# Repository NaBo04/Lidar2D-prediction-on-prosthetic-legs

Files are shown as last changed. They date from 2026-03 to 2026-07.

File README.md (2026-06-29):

# Contenido de este Repositorio :books:

    - Codgios: Contiene los códigos finales utilizados para la captura de datos, la ejecución, 
        construcción y entrenamiento de la red, el uso del dispositivo final, el entorno virtual.
        entre otros. 
    - DocumentosDeInvestigacion: Contiene los documentos externos utilizados durante el proyecto,
        como pueden ser datasheets, papers y documentos del curso.
    - DiseñosPCB: Archivos gerber de las versiones finales de las PCB usadas.
    - Entregables: Incluye los informes, presentaciones o similar, desarrollados por el equipo para
        las entregas del curso.
    - Modelos3D: Modelos diseñados para la implementación final de la muslera y la carcasa para la
        prótesis.

# Links importantes :rocket:

    - Notion (Carta Gantt): https://www.notion.so/Proyecto-de-t-tulo-3273d8bd994380379207d7b755e2225a
    - Drive (Videos): https://drive.google.com/drive/folders/1dMPfvoMqhFyon8SmyaXOXM7CERQkg4x7?usp=drive_link

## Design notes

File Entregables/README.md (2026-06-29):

\# Acá la presentación #

Link Video de Validación de Funcionamiento LIDAR: 
    https://drive.google.com/drive/folders/1dMPfvoMqhFyon8SmyaXOXM7CERQkg4x7?usp=sharing

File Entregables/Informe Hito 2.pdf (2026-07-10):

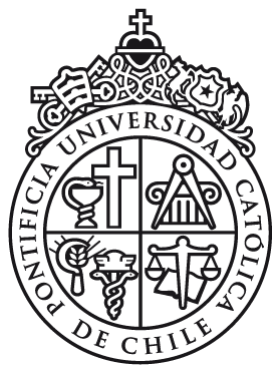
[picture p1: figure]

### PONTIFICIA UNIVERSIDAD CATOLICA DE CHILE ´

### ESCUELA DE INGENIERÍA

### DEPARTAMENTO DE INGENIERÍA ELECTRICA ´

# Informe final - Integración LIDAR 2D

# para Anticipación de Terreno en

# Prótesis Transfemoral Activa

PROYECTO DE TÍTULO - IEE3112

Profesor: Felipe Nuñez

Grupo 2

28 de junio del 2026

## Índice

1 Hito 1: Propuesta Conceptual y Diseño Funcional | 4
2 Hito 2: Prototipo | 21
2.4.2 | Detección y estimación de inclinación de rampas y del plano de suelo | 32

2.5 Validación de latencia extremo a extremo menor o igual a 200 ms | | 33
2.6 Métricas de error y matriz de confusión | | 33

2.7 Validación experimental en entorno controlado con medición de errores geométri-

cos | | 35
2.8 Repositorio GitHub documentado | | 36
2.9 Manual técnico de integración, arquitectura y pruebas | | 36
2.10 Presupuesto final | | 36
3 Anexo | 39

## Índice de figuras

Figura 1 | Diagrama de Bloques de Alto Nivel | | 4
Figura 2 | Leyenda | | 4
Figura 3 | Diagrama de Bloques de Bajo Nivel (Completo) | | 5
Figura 4 | Diagrama de Bloques de Bajo Nivel (Parte 1) | | 5
Figura 5 | Diagrama de Bloques de Bajo Nivel (Parte 2) | | 6
Figura 6 | Batería para validación experimental | | 8
Figura 7 | Diferentes topologías ML | | 15
Figura 8 | Representación de la pierna y su modelo asociado | | 16
Figura 9 | Curvatura de la pierna | | 17
Figura 10 | Soporte mecánico - Diseño 3D | | 17
Figura 11 | Soporte mecánico - Aplicación Física | | 18
Figura 12 | Soporte mecánico diseñado para la prótesis | | 21
Figura 13 | Solapas del soporte mecánico diseñado para la prótesis | | 22
Figura 14 | Diseño de Placas en Software EasyEDA | | 23
Figura 15 | Ambas PCB montadas una sobre otra en aplicación final | | 24
Figura 16 | Diagrama red iteración 1 | | 28
Figura 17 | Diagrama red iteración 2 | | 29
Figura 18 | Pagina Local para la Toma de Muestras | | 30
Figura 19 | Imágenes de Ejemplo de Adquisición de Datos | | 31

Figura 20 | Latencia | | 33
Figura 21 | Matriz de confusión sobre Test-dataset para datos binarios | | 34

## Índice de tablas

Tabla 1 | Especificaciones de componentes para integración de LIDAR en próte-
| sis transfemoral activa | | 13
Tabla 2 | Tabla con principales consumos | | 14
Tabla 3 | Presupuesto Hito 1 | | 20
Tabla 4 | Tabla con principales consumos | | 24
Tabla 5 | Etiquetado | | 27
Tabla 6 | Métricas de error para 100 épocas de entrenamiento | | 33
Tabla 7 | Presupuesto Hito 2 | | 38

## 1. Hito 1: Propuesta Conceptual y Diseño Funcional

### 1.1. Arquitectura general del sistema

La siguiente figura muestra el diagrama de bloques de alto nivel, el cuál entrega una primera

idea simplificada de cuál es el flujo del sistema en su totalidad. A modo de explicación, el

sistema inicia con un bloque de sensores que miden el entorno, los cuáles entregan medidas a la

Raspberry Pi 5. Esta se encarga del procesamiento de las medidas, la predicción mediante uso

de algoritmos de Machine Learning y la posterior comunicación para validación del usuario

monitor. El objetivo es que las predicciones sirvan para ejecutar una reacción por parte de

la prótesis, aunque se escapa de los objetivos de este proyecto. Finalmente, el sistema posee

su sub-sistema de alimentación, que le otorga independencia.

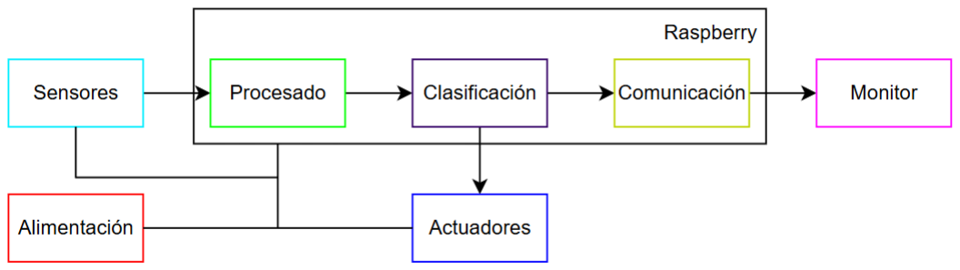
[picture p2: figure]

Figura 1: Diagrama de Bloques de Alto Nivel

Como se puede observar en la figura, los bloques siguen cierto código de colores, el cuál se

detalla en la leyenda a continuación.

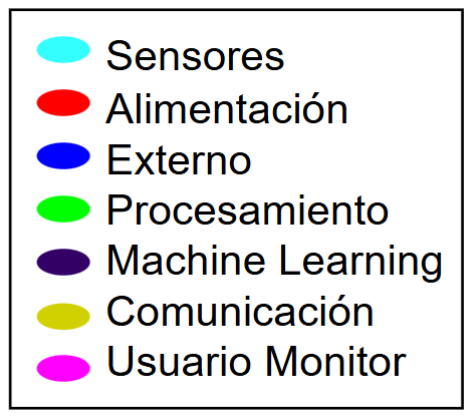
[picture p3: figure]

Figura 2: Leyenda

Una vez entendido el sistema de manera general, se puede proceder a analizar el diagrama

de bloques de bajo nivel. El cual, es escala macro, se ve como sigue. Luego, se detallará cada

sub-sistema con detenimiento.

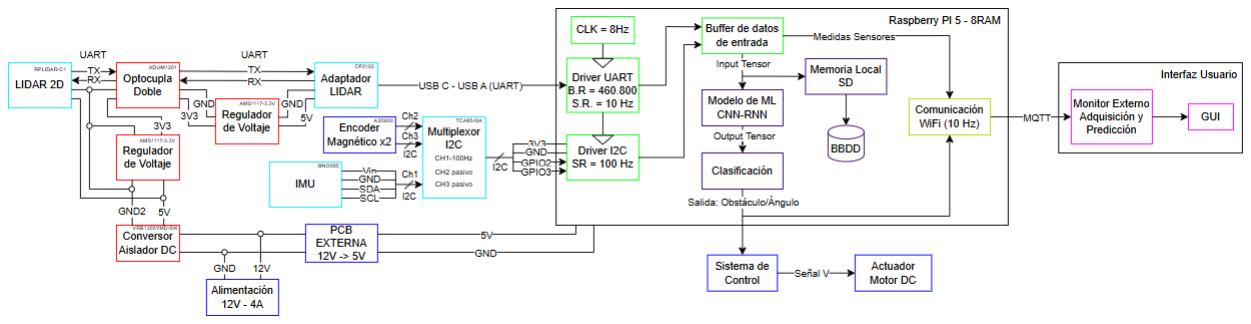
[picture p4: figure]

Figura 3: Diagrama de Bloques de Bajo Nivel (Completo)

Por motivos de la baja resolución de este en el informe, se procede a analizar el diagrama

por partes.

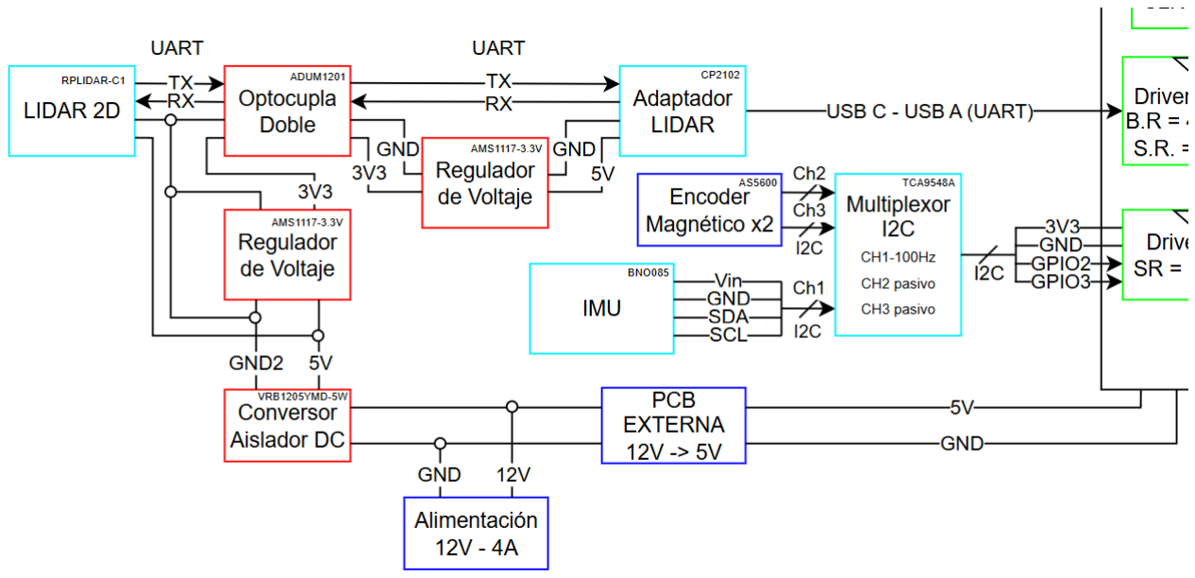
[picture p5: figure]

Figura 4: Diagrama de Bloques de Bajo Nivel (Parte 1)

La primera parte de este diagrama, incluye los bloques de sensores en color celeste, alimen-

tación y considera elementos externos. Esta parte es lo que concentra la mayor parte del

Hardware del sistema. En cuanto a los sensores, se aprecian el sensor principal: el LIDAR, la unidad de medición inercial (IMU) y sus adaptadores. Lo relacionado al LIDAR funciona

mediante protocolo UART, mientras que lo relacionado al IMU usa protocolo I2C. Por otra

parte, en color rojo, se encuentra lo relacionado a la alimentación. Estos bloques aparecen

principalmente para alimentar correctamente, y sobre todo proteger el sensor LIDAR y ais-

larlo contra posibles amenazas, por su sensibilidad y costo. Se explicará más en detalle en las

secciones correspondientes. Finalmente, en color azul, se encuentran elementos externos que

ya forman parte del proyecto, pero que decidimos tomar en consideración, para una correcta

cohesión con el desarrollo del proyecto. Estas son la alimentación de las baterías actuales, la

PCB del sistema de baterías y los encoders magnéticos.

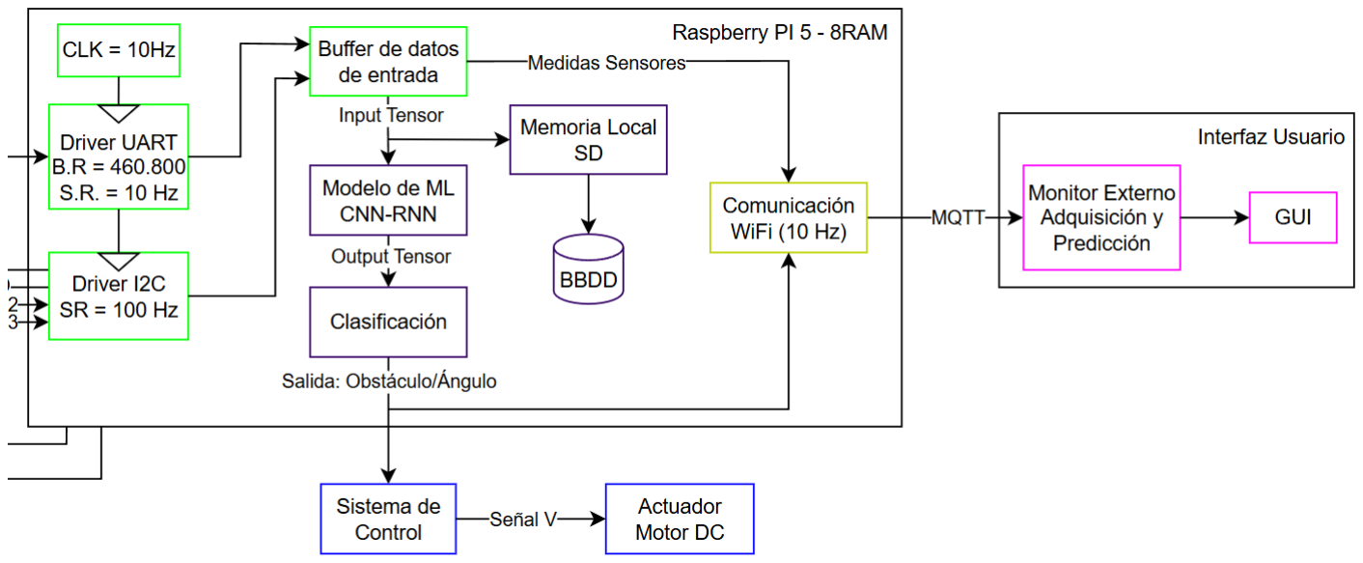
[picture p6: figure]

Figura 5: Diagrama de Bloques de Bajo Nivel (Parte 2)

La segunda parte de este diagrama incluye los sub-sistemas de procesamiento, predicción,

comunicación y monitoreo de usuario. La primera parte, en color verde, muestra la coordina-

ción de los 2 sistemas de adquisición de datos mediante los sensores, para formar los datos de

entrada para el modelo de red neuronal. Luego, en color morado, se encuentra lo relacionado

al algoritmo de predicción como tal, lo que incluye también la toma y guardado de datos

de forma local, para usarlos a lo largo del entrenamiento del modelo. En color amarillo, se

incluye el bloque de comunicación, que servirá durante las implementaciones finales y de-

bugueo correspondiente. Al final de la cadena, en rosado, está el bloque que corresponde al

monitoreo del sistema de forma remota, mediante una interfaz para el usuario. Por último, en la imagen se aprecian 2 bloques de color azul, que nuevamente son funciones externas al

objetivo del proyecto, relacionadas al sistema de reacción/actuación frente a la predicción.

### 1.2. Definición de bloques funcionales

### 1.2.1. Fuente de alimentación

La prótesis transfemoral activa ya cuenta con una batería integrada que alimenta la electróni-

ca de control existente. Esta misma fuente de energía será utilizada para suministrar potencia

a los nuevos subsistemas de percepción (LIDAR e IMU).

Dado que la batería ya se encuentra dimensionada y validada para la operación de la prótesis,

no es responsabilidad de este proyecto redefinir, reemplazar o caracterizar la fuente de ali-

mentación. En su lugar, nos enfocamos en asegurar que los nuevos componentes (RPLIDAR

C1 e IMU BNO085) sean compatibles con los niveles de voltaje y corriente disponibles en el

sistema existente.

La integración se realiza mediante un convertidor DC-DC aislado modelo VRB1205YMD de

12 a 5 V de 5 W, que permite adaptar la tensión de la batería a los requerimientos específicos

del LIDAR (4.8-5.2V a 260 mA típico) y para poder suministrar la corriente peak del Lidar

(1A en la partida). Este convertidor actúa como interfaz entre la fuente centralizada de la

prótesis y los nuevos sensores, protegiendo ambos subsistemas de variaciones en la tensión

de la batería. Mientras que la IMU (3-5V a 3-5 mA) se alimentará desde la misma fuente

utilizada por la Raspberry 5 Pi. Para las fases de prototipado y validación experimental, se

utilizará una batería portátil de 5000 mAh que proporciona conexión USB estándar y voltaje

de salida 5V.

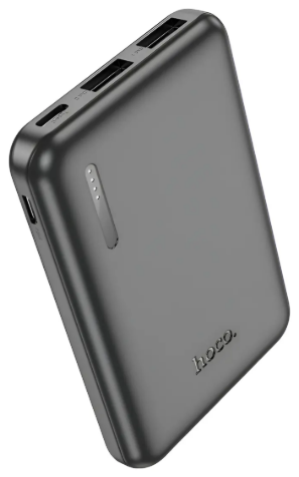
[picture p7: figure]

Figura 6: Batería para validación experimental

### 1.2.2. Módulo LIDAR 2D

Para este proyecto se utilizará el modelo RPLIDAR C1, el cual tiene un rango de medición

de 12 metros para objetos claros y de 6 para oscuros. Además, presenta una frecuencia de

muestreo de 5 kHz, un campo de visión 360° y una precisión de ± 30 mm.

Utiliza un puerto TTL UART con un baud rate de 460,800 bps para proporcionar información

de distancia (mm), ángulo (grados), señal de inicio de escaneo y datos de reflectividad (2.5D).

Los requerimientos de funcionamiento son principalmente una alimentación de 5 V y 230 mA.

El dispositivo es ligero, tiene un peso aproximado de 110 g, y es resistente a polvo y salpi-

caduras. Sin embargo, se debe tener la precaución de no exponer el láser directamente al sol

puesto que podría dañar irreversiblemente su funcionamiento.

### 1.2.3. Aislación del Módulo LIDAR 2D

Un LiDAR 2D es un sensor electromecánico de operación continua. Por esta razón, compartir

la misma referencia de tierra con una Raspberry Pi 5 puede ocasionar diversos inconvenientes.

El primero de ellos es la inyección de ruido electromecánico. Los motores, al ser cargas

inductivas, junto con su conmutación electrónica, generan picos de voltaje que se inyectan directamente en el plano de tierra. Otro problema importante son las corrientes de irrupción

(inrush), que consisten en corrientes transitorias de arranque capaces de provocar caídas

momentáneas de tensión, comprometiendo así la estabilidad de los rieles de alimentación de

la Raspberry Pi 5.

La solución a estos problemas es la aislación galvánica del motor con el sistema de control,

tanto para proteger el LIDAR 2D como la Raspberry Pi 5. Tal como se mencionó en etapas

anteriores, se utiliza un conversor DC-DC tipo Buck conectado en el lado de alto voltaje a

12V desde la batería (ya integrada en la prótesis) y en la lado de bajo voltaje a 5V conectado

a los rieles de alimentación del LIDAR 2D.

Para mantener el aislamiento galvánico en las líneas de comunicación entre la Raspberry Pi 5

y el LiDAR 2D, se implementará el aislador digital ADuM1201. Dado que los niveles lógicos

de salida de este módulo dependen exclusivamente de las tensiones aplicadas a sus rieles de

alimentación, y considerando que tanto el LiDAR 2D como el adaptador USB operan con

lógica de 3.3 V, resulta importante el uso de dos reguladores de tensión AMS1117-3.3 para

fijar dicho voltaje en ambos extremos del circuito.

### 1.2.4. Plataforma de procesamiento embebido (Raspberry Pi 5)

La Raspberry Pi 5 es una pequeño computador de bajo costo con un rendimiento sorprendente

para su tamaño. Su procesador cuádruple núcleo a 2.4 GHz la hace entre 2 y 3 veces más

rápida que la versión anterior, y su chip gráfico alcanza cerca de 0.077 TFLOPS, suficiente

para tareas de ML. Incluye WiFi de doble banda y Bluetooth 5.0, lo que facilita su conexión

inalámbrica en cualquier entorno. También estrena una ranura PCIe que permite conectar

discos SSD de alta velocidad, algo nunca visto en versiones anteriores. Con hasta 16 GB

de memoria RAM y un consumo eléctrico muy bajo, es ideal para proyectos embebidos,

automatización y computación en el borde de la red.

### 1.2.5. Sistema de comunicación

Los bloques funcionales presentados previamente necesitan transmitir datos entre ellos para

un correcto funcionamiento del sistema. En general los distintos bloques comunican o reciben datos desde la Raspberry, que actúa en este caso como nodo central del sistema. A conti-

nuación se enumeran las principales conexiones para la transmisión de datos y los protocolos

utilizados.

Conexión LiDAR → Raspberry:

La conexión entre estos dos nodos se realiza mediante protocolo UART con una conexión

micro-usb. Lo anterior se justifica debido a las especificaciones del LiDAR, ya que

transmite por defecto sus datos con protocolo UART. Además, el adaptador usb del

LiDAR facilita la conexión directa con la Raspberry a través de uno de sus puertos.

El formato en que se envían los datos será la distancia de la medición del láser del

LiDAR y el ángulo de este.

Conexión IMU → Raspberry El sensor IMU se conecta con la Raspberry a través de

protocolo I2C. Se eligió este protocolo debido a que es el que tiene el sensor por defecto,

además de ser simple y robusto de implementar para esta aplicación.

Un aspecto relevante a tener en cuenta es que el sensor no se conectará directo a

terminales I2C de la Raspberry, debido a que estos están siendo utilizados por otros

sensores que son parte de la implementación de la prótesis, pero externos a este proyecto.

Debido a lo anterior, se utilizará un multiplexor I2C al que se conectará otro sensor

además del IMU, de tal forma que puedan compartir un solo puerto I2C de la raspberry.

El multiplexor a utilizar se conectará a los 3 sensores y a un solo puerto de la raspberry.

Cómo se pudo observar en el diagrama de bloques inicial, los tres sensores serían dos

encoders magnéticos y el IMU, la estrategia para que coincidan los tiempos del LiDAR

y el IMU es utilizar el Lidar a 10 Hz y el IMU a 100 Hz una vuelta completa (ambos

se pueden utilizar en estas configuraciones de muestreo).

De esta forma, el multiplexor escuchará principalmente al IMU enviando mediciones

cada 100 Hz. Luego, cada 10 Hz, se enviarán las muestras del encoder para que coincidan

con las mediciones del LiDAR, coordinandose de esta forma la utilización del puerto

I2C, las mediciones del IMU y la medición del LiDAR con sus respectivas frecuencias

de muestreo.

Los datos que se recibirán del IMU corresponden a la posición relativa del LiDAR

respecto a cierto marco de referencia. Esta medición se envía mediante quaterniones,

dado que el dispositivo utilizado tiene la capacidad de enviar sus datos directamente

en este formato.

Conexión Raspberry ↔ Interfaz de monitoreo:

El objetivo de esta conexión es enviar los datos de medición del LiDAR y el IMU, además

de las clasificaciones realizadas por el modelo de Machine Learning a una plataforma

externa donde se pueda monitorear el funcionamiento de la prótesis.

Para esta funcionalidad se transmitirán los datos vía WiFi con protocolo MQTT. La

razón de esto es que se necesita una transmisión inalámbrica de los datos, por lo que

se decidió utilizar el módulo WiFi que tiene integrado la Raspberry.

Por otro lado, se eligió el protocolo MQTT debido a las características de la aplicación,

este protocolo está pensado para dispositivos IoT donde el envío de datos se realiza

en condiciones de redes inestables y anchos de banda limitados, además permite una

lectura simple de los datos desde otros dispositivos como un ordenador o una página

web para mostrar los datos recibidos en tiempo real.

Los datos se enviarán cada vez que el modelo realice una clasificación, el formato de

envío de los datos será la clasificación con el tipo de obstáculo y características como

ángulo de inclinación en caso de una rampa y altura del escalón en caso de una escalera.

Sumado a lo anterior, se enviará en el mismo paquete las entradas del LiDAR y el IMU

con las que se realizó la clasificación.

### 1.2.6. Almacenamiento y monitoreo de datos

Como se observa en el diagrama de bloques de bajo nivel del sistema, los datos tienen dos

destinos, un almacenamiento en la Raspberry y un envío remoto mediante WiFi y MQTT

que fue adelantado en la sección anterior, y hacia el bloque controlador de la prótesis. En

esta sección se explicarán más a detalle ambos destinos de los datos luego de la clasificación.

Almacenamiento local: Su objetivo es almacenar únicamente las mediciones del Lidar

y el Imu para posteriormente seguir entrenando al modelo con estos datos. El almace-

namiento se realiza en una base de datos local dentro de la raspberry en su tarjeta SD,

para posteriormente cargarlos en otro dispositivo y trabajar con ellos.

Envío remoto para monitoreo: Este flujo de datos es el que se explicó en la sección

anterior. El objetivo es que cada cierto envíe las clasificaciones realizadas y los datos

de entrada con los que realizó la clasificación.

Para este proyecto, estos datos serán leídos desde el Broker MQTT desde un compu-

tador que generará una interfaz gráfica local con un script en Python. El objetivo de

esto es mostrar de una forma amigable y útil para trabajar los datos en los experimentos

para testear el funcionamiento de la implementación del proyecto.

Cabe destacar que si bien la implementación de la interfaz gráfica mediante la lectura

de datos desde un computador, gracias a la arquitectura MQTT es posible también

escalar hacia una página web donde se lean los datos en tiempo real, sin embargo, esto

escapa del proyecto y se puede implementar en una etapa más avanzada de la prótesis.

Controlador: Finalmente, el controlador de la prótesis que envía la acción de control

al motor actuador, recibe únicamente la clasificación de obstáculos realizada por el

modelo, donde recibe el tipo de obstáculos y datos relevantes como la altura del escalón

si el obstáculo es una escalera, el ángulo de inclinación si es una rampa, entre otros.

Este bloque aún no está implementado y no forma parte del proyecto actual, por lo que

solo se define cómo recibirá los datos.

### 1.3. Especificación y definición de componentes

Componente | Modelo/Especificación | Parámetros Clave
Sensor LIDAR 2D | RPLIDAR C1 (C1M1-R2) | Alcance: 0.05–12 m Frecuencia: 10 Hz @ 600 RPM Resolución: 0.72° Precisión: ±30 mm Peso: 110 g
IMU 9-DOF | Adafruit BNO085 | Acelerómetro: ±16 g Giroscopio: ±2000°/s Magnetómetro: ±4900 µT Interfaz: I²C/UART/SPI Fusión sensorial: Cortex-M0 Voltaje entrada: 3–5 V DC Consumo: ∼3–5 mA típico Precisión angular: ±2°
Interfaz LIDAR | UART TTL 3.3V XH2.54-5P | Velocidad: 460800 bps Modo: 8n1 Tensión salida: 0–3.5 V
Procesador | Raspberry Pi 5 Model B | CPU: BCM2712 Quad-Core ARM Cortex-A76 Frecuencia: 2.40 GHz Arquitectura: 64-bit aarch64 RAM: 8 GB GPU: Broadcom VideoCore VI Sistema operativo: Debian GNU/Linux 13 (Trixie) Kernel: Linux 6.12.75+rpt-rpi-2712 Compatible con ROS 2

Tabla 1: Especificaciones de componentes para integración de LIDAR en prótesis transfemoral activa

A continuación se presenta una tabla con los consumos energéticos principales de los com-

ponentes de la implementación. El resto de componentes de este proyecto no se tomaron en

cuenta debido a que sus consumos son despreciables en relación a los que se presentarán a

continuación:

Esta tabla permite calcular la autonomía de la batería del sistema implementado en este

proyecto, así como el de la prótesis en su totalidad al considerar los consumos del resto de

Componente | Consumo (W)
Sensor LiDAR 2D | 1.35 W
Conversor DC-DC Aislado (pérdida por conversión) | 0.25 W
Raspberry PI | 10 W

Tabla 2: Tabla con principales consumos

bloques ya implementados en la prótesis.

Considerando que el power bank utilizado para las pruebas tiene una capacidad de 5000

mAh, la autonomía de la batería es de aproximadamente 2 horas y 10 minutos.

### 1.4. Procesamiento y clasificación de datos

Existen diversas topologías enfocadas en nubes de puntos para detectar objetos como Point-

Net o PointNet++ las cuales usan simplemente MLP. Ahora, estas topologías simples no

aprovechan el hecho de que el Lidar entrega los datos en forma ordenada r(θ) por lo que los

modelos propuestos usan CONV1D para aprovechar estas ventanas de datos, los cuales al

ser cercanos proporcionan cierta información que puede ser captada por un kernel de convo-

lución. Por otro lado no se usa CONV2D porque sería entregar la nube de puntos como una

imagen, lo cual aumenta el tiempo de procesamiento.

En base a esto, los papers siempre usan como capa base las convolucionales 1D, adoptando

diversas cantidades de neuronas, max pooling, agregando más información al input como

pueden ser los datos de un IMU, o agregando capas con memoria como RNN, GRU o STM.

Todo depende de la dificultad que se quiere conseguir como output de la red.

A continuación se presentan dos modelos, los cuales tienen diversos fines y grados de dificultad

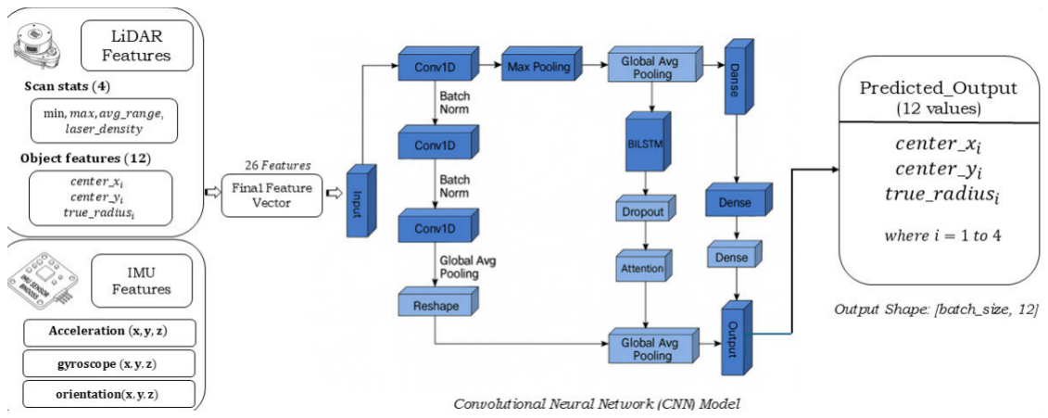
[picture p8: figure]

2D LaserNet | CNN+TSM

Figura 7: Diferentes topologías ML

La primera imagen es una red muy simple, la cual transforma los datos r(θ) → (x, y) de

ahí el input NX2, cada uno de ellos se procesa con capas CONV1D por rapas separadas,

aplican max pooling para reducir dimensionalidad quedándose solo con datos importantes,

finalmente condensan todo y se procesa por la típica MLP. Esta red extrae diversas clases,

y fue creada para la detección de elementos como corredores, pasillos, piezas, puertas, entre

otras. Se consigue un accuracy superior al 95 % con excepción de las puertas. La detección

ocurre en tiempo real y puede ser usada sobre robots para el monitoreo del entorno.

La segunda imagen implementa los datos del Lidar en conjunto con el IMU, acá los datos se

procesan para conseguir distintos parámetros, los cuales se suman a una estimación de los

objetos cercanos y los datos del IMU dando vector de 26 entradas como input. La idea es

estimar la posición (x,y) y el radio de un objeto. Esta red es muy precisa e implementa una

capa STM para agregar memoria al sistema, de esta forma la red sabe de alguna manera que

el objeto o el robot pueden estar en movimiento y lo considera debido a que su salida no es

una simple clasificación, si no que la dimensionalidad y la posición también.

El modelo propuesto considera el punto medio entre ambos puntos, considerando capas con-

volucionales 1D como base y probar métodos como:

Input coordenadas r(θ) con información de IMU

Input coordenadas (x, y) con información de IMU considerando procesamiento por ca-

pas separadas

Probar distintas cantidades de capas, neuronas, agregar GRU o RNN y generar un

trade off entre tiempo de procesamiento, uso de la CPU y accuracy, para saber si vale

la pena en este contexto agregar memoria a la red o no.

### 1.5. Diseño del soporte mecánico

Para el soporte mecánico se diseño una rampa que pudiera corregir la inclinación de la pierna

y de esta forma se orientara el laser de forma tal que este perpendicular al suelo. Para calcular

el angulo de inclinación se utilizó una foto de referencia, se dibujó un triangulo rectángulo y

se midió digitalmente los largos de sus catetos. Posteriormente, se utilizaron dichos valores y

se obtuvo un angulo de 6.12°.

Dibujo esquemático de

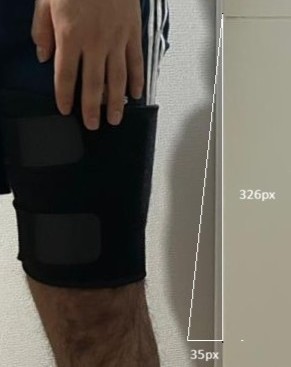
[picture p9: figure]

la pierna. | Cálculo de la pendien-
| te.

Figura 8: Representación de la pierna y su modelo asociado.

También fue necesario calcular la curvatura natural de la pierna para que el soporte calce de

la manera más ergonómica posible. Para esto se utilizó papel aluminio y se moldeó la forma

de la pierna a la altura donde se ubicará posteriormente el LiDAR. El radio del circulo que

define esa curvatura es 166.73 mm.

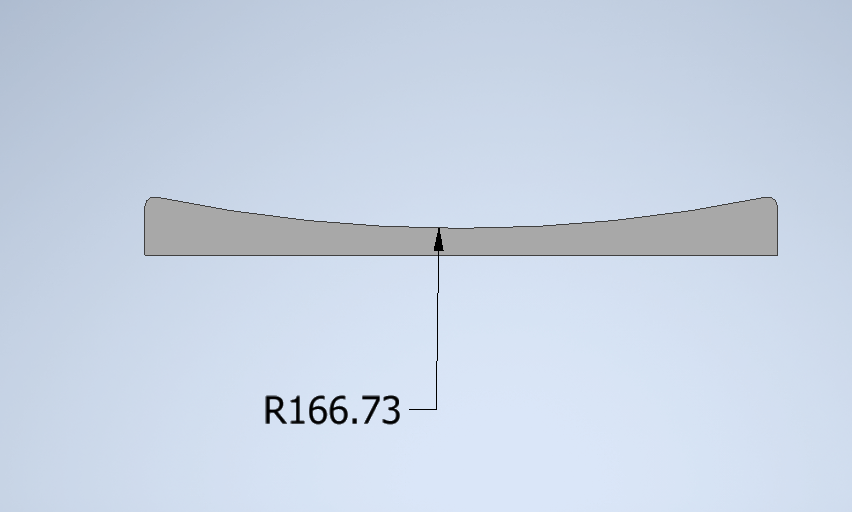
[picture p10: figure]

Figura 9: Curvatura de la pierna.

A continuación se adjuntan los modelos diseñados.

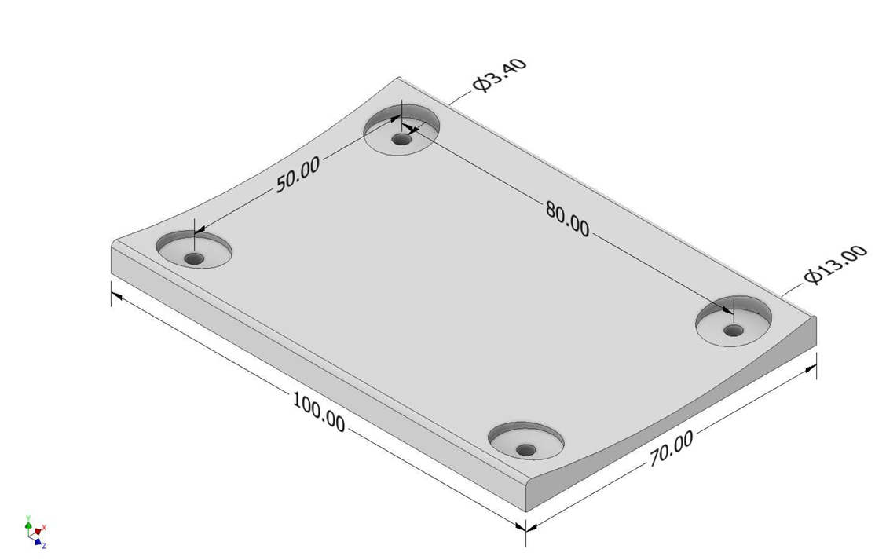
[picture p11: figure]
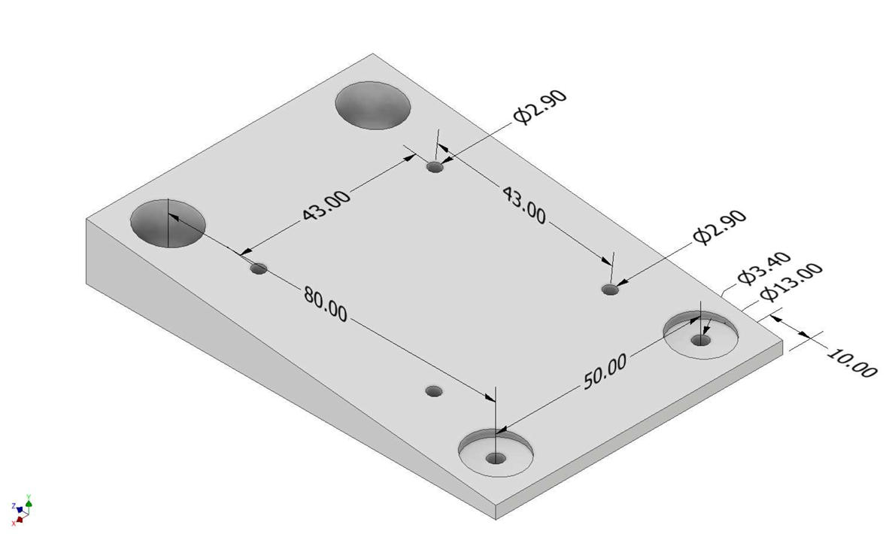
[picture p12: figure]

Base curvada para soporte a la pierna. | Rampa de nivelación para el láser.

Figura 10: Soporte mecánico - Diseño 3D.

Finalmente, se adjunta la pieza renderizada, impresa y montada.

Piezas renderizadas

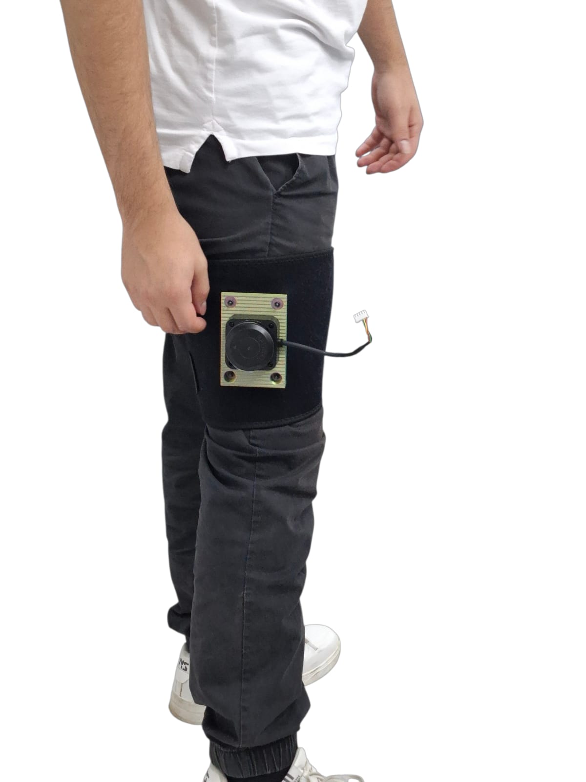
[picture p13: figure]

Montaje de Pruebas en Físico

Figura 11: Soporte mecánico - Aplicación Física.

### 1.6. Presupuesto inicial

Para el desarrollo de este proyecto se estima que se necesita contemplar el presupuesto,

expuesto en la tabla 3, para construir el prototipo inicial.

Descripción | Precio | Comentarios/Justificación
Banda de compresión mus- lera | $11.100 | Soporte para pruebas: en esta banda
| | se montará el sistema del LiDAR para
| | realizar pruebas previas a la propuesta
| | de instalación del sensor en la prótesis.
Filamento Impresión 3D PLA 1.75 mm 2 kg | $26.000 | Soporte para pruebas: se necesita im-
| | primir el soporte donde montaremos el
| | LiDAR y demás componentes del siste-
| | ma junto al agarre a la banda.

Kit 830 Puntos de Co-

nexión | Componentes
Electrónicos | $10.760 | Soporte para pruebas: se necesitan
| | componentes varios para hacer pruebas
| | y prototipos.
| | Continúa en la siguiente página...

Tabla 3 – Continuación de la página anterior

Descripción | Precio | Comentarios/Justificación
Tornillos M2.5 8 mm (100 uds) | $6.581 | Soporte para pruebas: para unir las dos partes del prototipo 3D que agarran a la banda.
Velcro Autoadhesivo | $7.480 | Soporte para pruebas: se utilizará pa- ra poder remover y ubicar fácilmente la batería en la banda utilizada. Se pe- gará una banda de velcro a la batería que usaremos para alimentar el sistema con el objetivo de que sea más simple cargarla.
Batería de alimentación | $11.790 | Soporte para pruebas: se utilizará para alimentar el sistema (5000 mAh).
IMU BNO085 | $28.678 | Implementación: se utilizará para de- terminar el ángulo de inclinación de la pierna en tiempo real. Comentario: no se encontró un proveedor local confia- ble y a un precio razonable.
Conversor 12V-5V | $4.205 | Alimentación aislada LIDAR 2D.
Raspberry Pi 5 shield | $6.280 | Solicitado por la contraparte para ma- yor modulación en la aplicación.
Nivel Digital | $26.432 | Permite aislar la linea de comunicación entre LIDAR 2D y Raspberry Pi 5
Aislador | Digital
ADUM1201 | $2.158 | Para realizar mediciones confiables y precisas de niveles de inclinación para validar las pruebas y resultados.
| | Continúa en la siguiente página...

Tabla 3 – Continuación de la página anterior

Descripción | Precio | Comentarios/Justificación
Módulo Regulador de Vol- taje 3.3V AMS1117 | $2.456 | Permite reducir voltaje de 5V a 3.3V

Multiplexor I2C de 8 Ca-

nales TCA9548A

$2.983 | Controlar el uso de Comunicación I2C
Total | $146.903

Tabla 3: Presupuesto Hito 1

## 2. Hito 2: Prototipo

### 2.1. Integración mecánica y electrónica del LIDAR 2D en la próte-

### sis

### 2.1.1. Soporte mecánico

Se diseñó una pieza 3D para sostener el LiDAR y las PCBs en una misma posición independiente

del movimiento de la prótesis, esta ubicación se presenta a continuación.

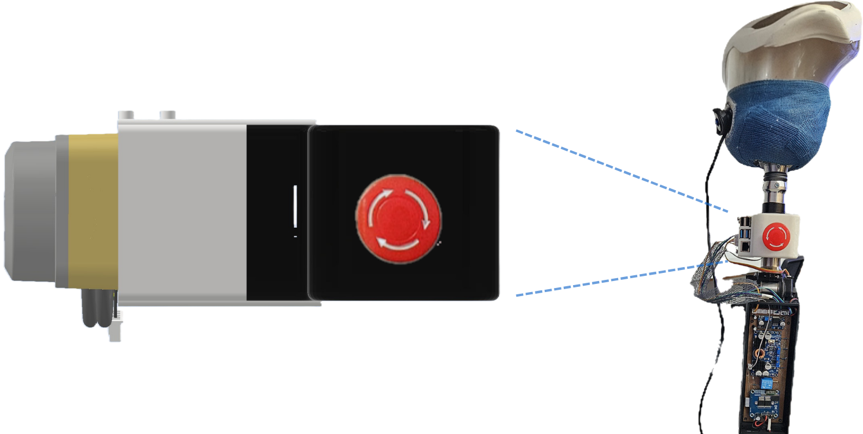
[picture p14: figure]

Figura 12: Soporte mecánico diseñado para la prótesis.

La pieza diseñada es una caja que en su interior contiene las PCBs previamente fijadas con los

espaciadores, mientras que en su exterior tiene fijado con pernos el LiDAR. Además, para fijar esta

pieza a la prótesis se diseñaron unas solapas, como se muestra en la figura 13, en donde se ubicarán

unos tornillos de soporte.

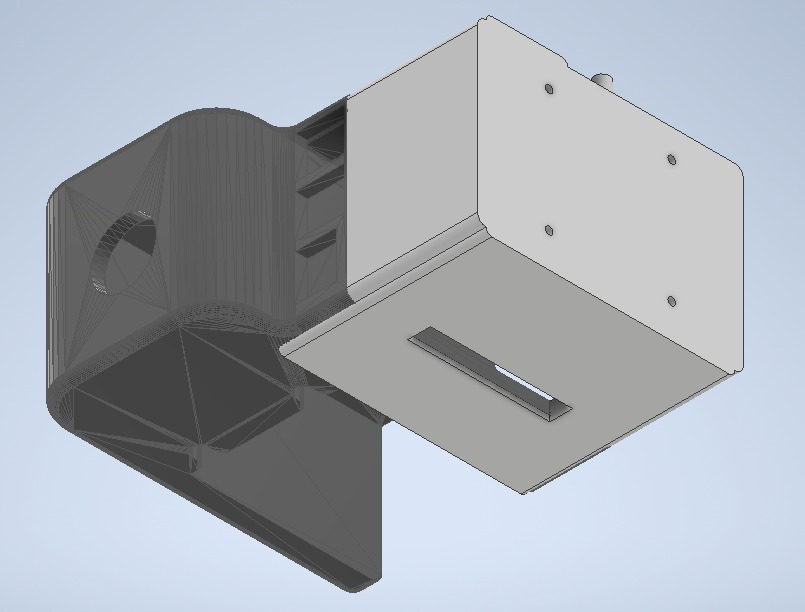
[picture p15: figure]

Figura 13: Solapas del soporte mecánico diseñado para la prótesis

### 2.1.2. PCB

Se desarrollaron las siguientes dos placas para suplir las funciones de protecciones eléctricas, coor-

dinación de sensores e incorporación apropiada al prototipo ya diseñado por la contraparte. Estas

se exponen y detallan a continuación.

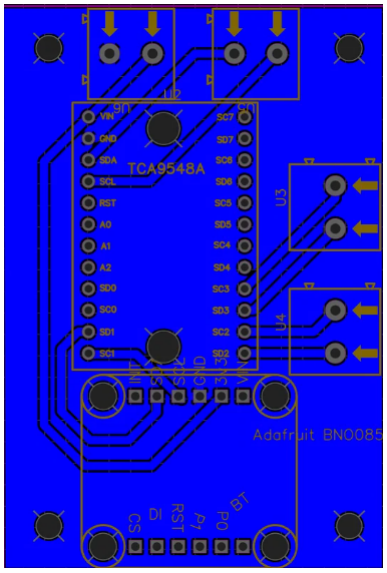
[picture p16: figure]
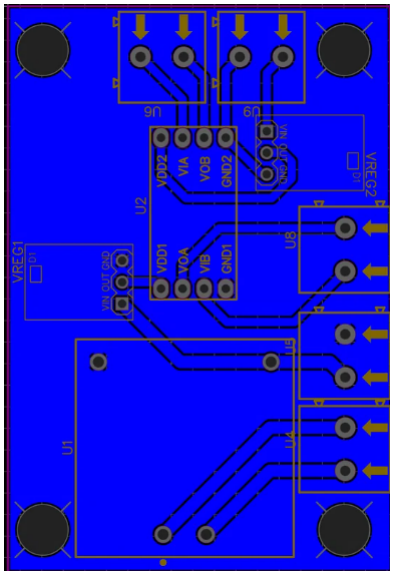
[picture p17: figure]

(a) PCB superior - IMU y MUXI2C | (b) PCB inferior - Reguladores y Protecciones

Figura 14: Diseño de Placas en Software EasyEDA.

La primera placa, se organiza en torno al multiplexor de bus I²C TCA9548A. Como las unidades

inerciales BNO085 comparten una misma dirección I²C fija y no pueden coexistir en un mismo bus,

el multiplexor habilita un canal a la vez y permite leerlas de forma secuencial sin conflictos. Así se

obtienen varias referencias de orientación del segmento de la prótesis, que el sistema utiliza para

discriminar entre escaleras, rampas y obstáculos. La alimentación y el bus I²C llegan a esta placa

ya aislados desde la primera, de modo que el aislamiento galvánico se mantiene a lo largo de todo

el trayecto.

La segunda placa, toma los 12 V de la batería y los reduce a 5 V mediante un conversor Buck,

generando dos rieles independientes a ambos lados de la barrera de aislamiento. El integrado U2

aísla las líneas de comunicación entre ambos dominios, separa el lado primario (VDD1/GND1, ligado

a la batería) del lado secundario (VDD2/GND2, ligado a los sensores), de modo que la electrónica

de adquisición no comparta tierra con el lado de potencia.

Ambas placas fueron diseñadas para montarse la una sobre la otra, con tal de aprovechar al máximo

el espacio y, sobre todo, adaptarse al prototipo ya implementado por la contraparte en la prótesis.

Estas se unieron mediante elementos de tornillería para aplicaciones de PCB. En la imagen se

pueden observar ambas PCB y su distribución antes de ser incorporadas en la carcasa diseñada.

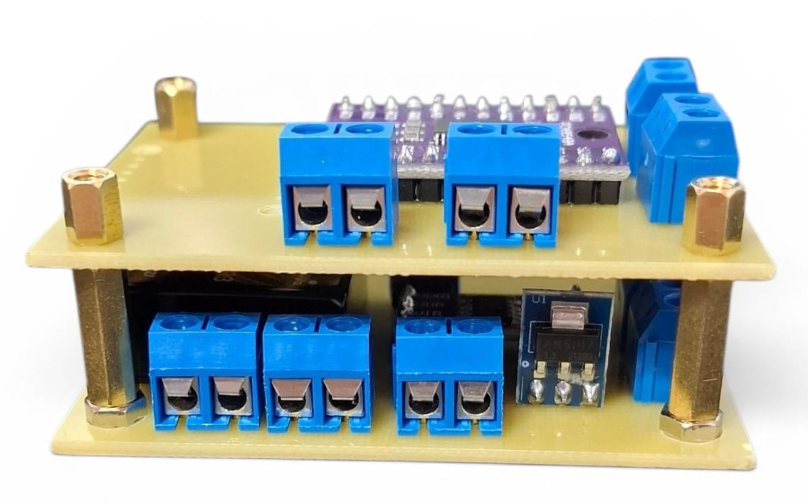
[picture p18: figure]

Figura 15: Ambas PCB montadas una sobre otra en aplicación final

### 2.1.3. Consumo estimado

Componente | Consumo (W)
Sensor LiDAR 2D | 1.35
Conversor DC-DC Aislado (pérdida por conversión) | 0.25
Raspberry PI | 10
Multiplexor TCA9548A | 0.7
Regulador de voltaje AMS1117 5V A 3.3 v (x2) | 0.06
Aislador UART ADUM1201 | 0.0264

Tabla 4: Tabla con principales consumos

### 2.2. Implementación de sistema

El código implementado para el funcionamiento del sistema, se realizó mediante el lenguaje de

programación Python. Este consta de tres scripts, el principal denominado ”script red IMU LI-

DAR.py”,contiene la base para el funcionamiento de los sensores IMU y LIDAR, en conjunto con

el procesamiento de la información y la inferencia de la red neuronal en tiempo real.

Para asegurar el cumplimiento de la condición de latencia, se decidió optar por la utilización de dos

de los cuatro núcleos disponibles de la Raspberry Pi 5. Para ello se utilizó funciones de la librería

multiprocessing.

Uno de los núcleos, se utiliza exclusivamente para la adquisición de la información, tanto de la IMU

como el LIDAR, mientras que el segundo, se utiliza para el filtrado y procesamiento de los datos,

además de la inferencia en tiempo real de la red neuronal diseñada.

### 2.2.1. LIDAR C1

El LIDAR C1 se conecta a la Raspberry Pi 5 mediante puerto serie USB y opera de forma continua.

Cada vuelta produce un conjunto de puntos con ángulo y distancia medida, que varía en cantidad

según la velocidad de giro y la tasa de muestreo del sensor. Al completarse cada vuelta, los puntos

se ordenan según su ángulo y se interpolan a un vector fijo de 450 entradas, correspondientes a

ángulos uniformemente espaciados cada 0,8° entre 0° y 359,2°, donde los valores de las entradas

corresponden a las distancias medidas por el LiDAR. Los ángulos sin distancia asignada o con falta

de angulos superiores a 5° se rellenan con la distancia máxima del sensor (12.000 mm o 12 m).

Antes de la interpolación de los datos, el escaneo del LiDAR se corrige geométricamente usando

el vector de gravedad entregado por el IMU BNO085. Esta corrección rota el eje de referencia del

escaneo para compensar la inclinación actual de la prótesis, de modo que el plano del suelo quede

siempre en la misma posición angular relativa independientemente de la postura del dispositivo.

El vector de 450 distancias nivelado y normalizado es la entrada a la red neuronal, que produce

como salida tanto clasificaciones binarias de obstáculos como las respectivas distancias o ángulos si

aplica el caso.

### 2.2.2. IMU BNO085

El sensor BNO085 se comunica con la Raspberry mediante el bus I²C. Se utilizan tres mediciones del

sensor: acelerómetro (BNO REPORT ACCELEROMETER en código), giróscopio (BNO REPORT GYROSCOPE

en código) y vector de gravedad (BNO REPORT GRAVITY en código). Este último es estimado por

el propio BNO085 mediante su algoritmo de filtro de Madgwick, el cual filtra las componentes

dinámicas de la aceleración para entregar únicamente la componente gravitacional estática.

La lectura del sensor se ejecuta en un hilo secundario dentro del proceso de adquisición de datos, corriendo a una frecuencia de 100 Hz. En cada iteración se leen las tres tuplas (x, y, z) del

acelerómetro, giróscopio y vector de gravedad.

Para suavizar el ruido en las lecturas del vector de gravedad, se aplica un filtro de promedio móvil

con una ventana de 10 muestras, independiente para cada eje del vector de gravedad.

Los valores filtrados se almacenan en un diccionario global compartido, junto con las lecturas crudas

del acelerómetro y del giróscopio. Este diccionario es utilizado por el hilo principal al completar

cada vuelta del LiDAR para luego realizar la corrección de las mediciones.

### 2.2.3. Red Neuronal

El modelo de machine learning fue desarrollado para lograr estimar características espaciales del

entorno, como:

Obstáculos frontales/traseros

Rampas con su respectiva inclinación

Escaleras con la respectiva altura del escalón

Para generar estas etiquetas, durante la adquisición de datos (la cual se ahonda más adelante

en [2.3]), se asignaron tanto etiquetas discretas, para la detección de obstáculos, como etiquetas

continuas para la estimación de características físicas de los obstáculos. Se utilizaron 9 etiquetas en

total para reducir la cantidad de neuronas a la salida de la red, y como consecuencia, la cantidad

de multiplicaciones y tamaño de la misma.

Etiquetado | Tipo | unidad | comentarios
superficie frontal | Binario | - | Corresponde a cualquier superficie con una inclinación positiva, negativa o nu-la frente al usuario. Rampas y Suelos
superficie trasera | Binario | - | Corresponde a cualquier superficie con una inclinación positiva, negativa o nu-la detrás del usuario. Rampas y Suelos
escalón frontal | Binario | - | Corresponde a un peldaño o escalera que se encuentre frente al usuario.
escalón trasero | Binario | - | Corresponde a un peldaño o escalera que se encuentre detrás del usuario.
obstáculo | Binario | - | Corresponde a cualquier superficie con más de |15°| de inclinación, u objeto/-peldaño que supere los 30cm de altura, o directamente una pared o similar.
ángulo superficie frontal | Flotante | ◦ ] [ | Angulo que varía entre -15 ´ ° y 15°. Es-calado entre 0 y 1.
ángulo superficie trasera | Flotante | ◦ ] [ | Angulo que varía entre -15 ´ ° y 15°. Es-calado entre 0 y 1.
altura escalones | Flotante | [cm] | Altura que varía entre 1 cm y 30 cm. Escalado entre 0 y 1.
distancia obstáculo | Flotante | [m] | Distancia que varía entre 30 cm y 3 m. Escalado entre 0 y 1.

Tabla 5: Etiquetado.

Por otra parte, se pensaron dos tipos de redes, cada una diseñada según los inputs que recibían.

La red de iteración 1, la cual se puede apreciar en la figura[16], considera tanto los 450 puntos

del Lidar interpolados con todas las características descritas en las secciones anteriores. Junto a

estas mediciones, se sumaron las del IMU como información adicional a la red, específicamente

acelerometro, giroscopio, gravedad (cada uno con sus ejes xyz), roll y pitch.

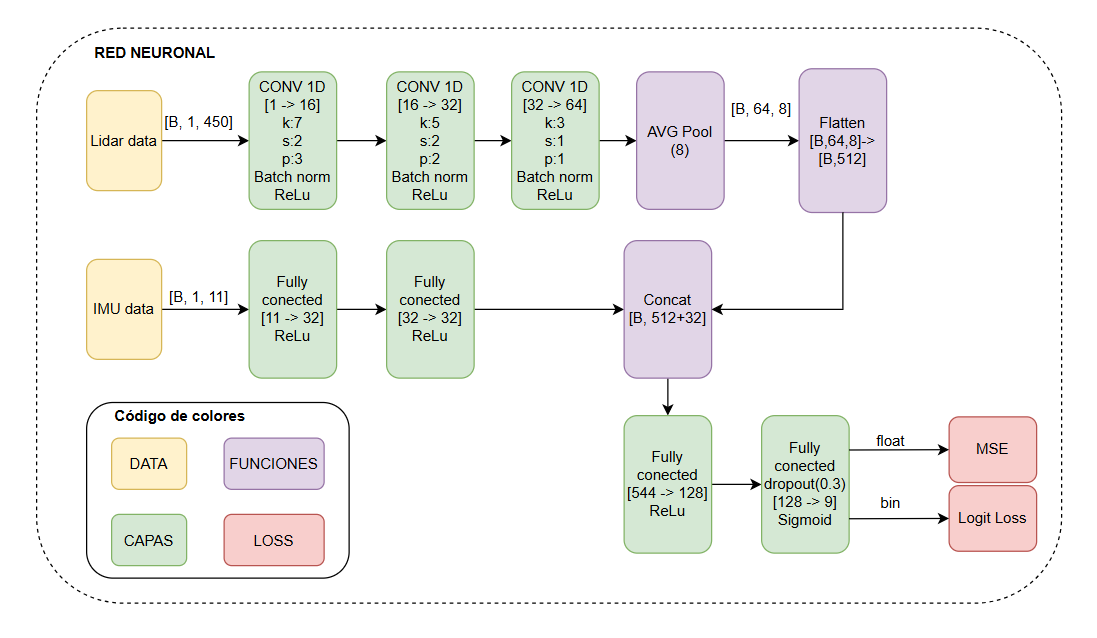
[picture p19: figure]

Figura 16: Diagrama red iteración 1

Como se puede apreciar de la figura anterior, los datos del Lidar se pasaron por capas convoluciona-

les, mientras que los del IMU por capas densas. Esto es debido a la correlación espacial que hay en

las 450 muestras del Lidar las cuales son aprovechadas de mejor manera con redes convolucionales,

mientras que las del IMU no son un array espacial de datos, solo mediciones. También, destacar

que se separaron las etiquetas para pasar a la función de error, esto porque, al ser comparadas con

etiquetas de distinta naturaleza, tienen que pasar por funciones de error distintas. Específicamente,

a través de la librería Pytorch, se usaron las funciones de error BCEWithLogitsLoss y MSELoss

para los datos binarios y flotantes respectivamente. Ambas funciones de pérdida se sumaron para

ser computadas por la red.

La segunda red que se probó sin los datos del IMU. Se usaron las mismas características de etiquetado

descritas y las mismas funciones de error para entrenar la red. En este caso, el input son las 450

muestras del Lidar, interpoladas, pero normalizadas por la el IMU. El diagrama de la red iteración

2 se puede apreciar en la siguiente figura ([17]).

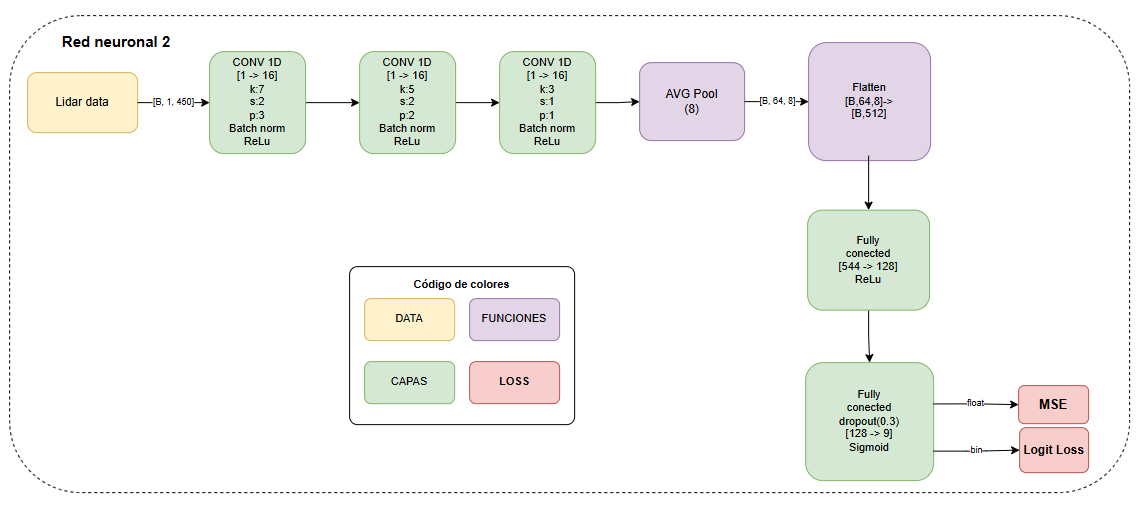
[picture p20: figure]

Figura 17: Diagrama red iteración 2

Los resultados de entrenamiento, Loss, Validation Loss, Accuracy, pruebas en tiempo real y limita-

ciones se presentan en las siguientes secciones.

### 2.3. Adquisición de datos

Para llevar a cabo la adquisición de datos se utilizó un script de Python capaz de realizar las capturas

y etiquetarlas en el momento, mediante las indicaciones de la persona que mide. Para facilitar y

agilizar el proceso de toma de muestras, el código considera una interfaz web local, que permite

observar en el momento las mediciones del sensor LIDAR, en sus tres formas (ver figura): medidas

crudas, estabilizadas mediante IMU e interpoladas con limitación de máximo para estandarizar las

medidas. La interfaz permite conservar las etiquetas del último registro, lo que acelera el proceso y

permite seguir los movimientos capturados en tiempo real.

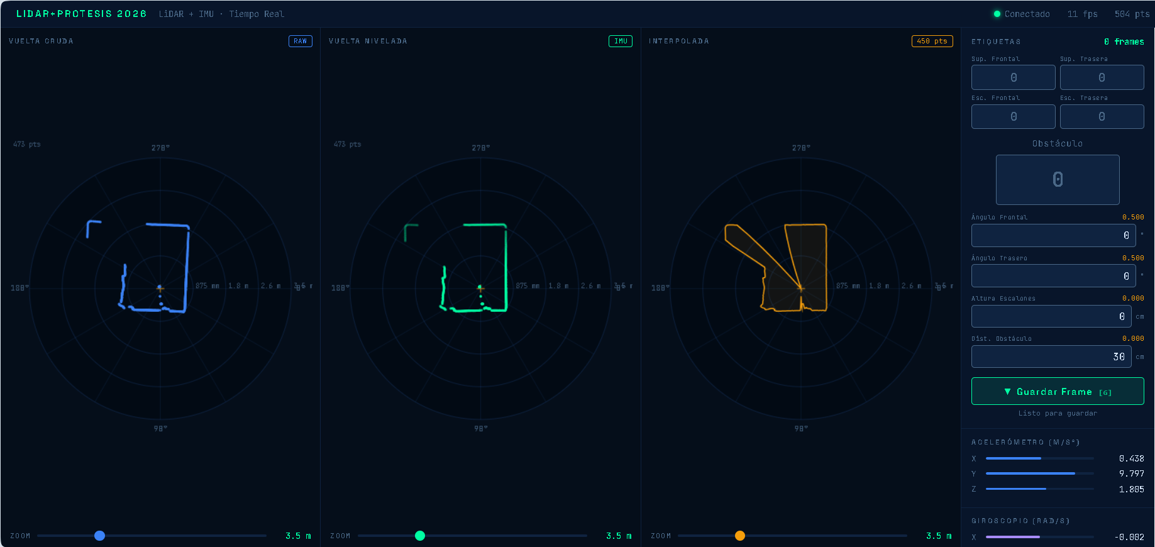
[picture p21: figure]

Figura 18: Pagina Local para la Toma de Muestras

Se escogieron más de 50 lugares dentro del campus para servir como puntos de toma de muestras.

Siendo todos estos de naturaleza variable, contemplando diversos tipos de suelos, rampas, escaleras

y obstáculos. Variando entre distancias, ángulos y tamaños de cada escenario, según corresponda.

También se consideraron espacios cerrados y abiertos, con alta y con baja iluminación, exteriores

diurnos y nocturnos, con tal de abarcar la mayor cantidad de casos posibles.

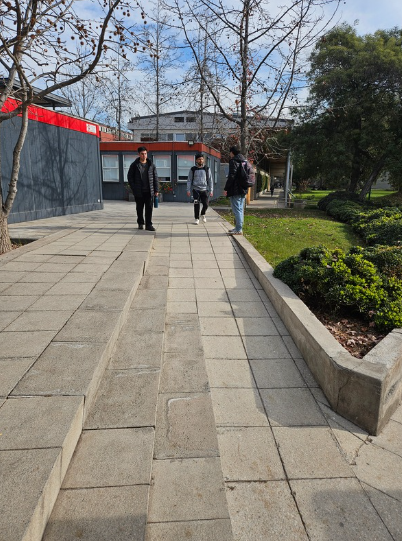
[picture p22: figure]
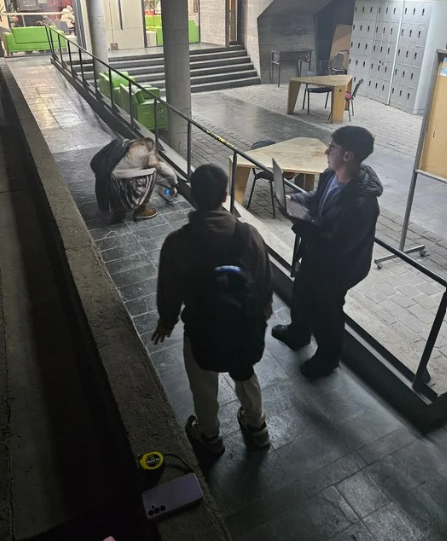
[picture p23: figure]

(a) Ejemplo de lugar Nocturno e Interior | (b) Ejemplo de lugar Diurno y Exterior

Figura 19: Imágenes de Ejemplo de Adquisición de Datos

Se buscó iterar entre 30 y 60 muestras distintas por cada lugar, consiguiendo así un total de 2630

capturas. Las muestras fueron tomadas de manera estática (análogo a posar para una foto durante

unos segundos), variando entre ellas el ángulo del LIDAR con respecto al piso, la distancia al mismo,

la distancia a objetos, rapas y escalones. Esto con tal de simular las distintas posiciones del sistema

durante una caminata continua. Para el etiquetado se utilizaron como instrumentos de medición una

cinta métrica y un nivel digital. El proceso se maximizó en eficiencia cuando, además del sujeto que

utilizó el dispositivo de captura, había un encargado de medir distancias y tamaños, otro encargado

de medir ángulos, y un último tomando y etiquetando capturas mediante la interfaz. Por lo que el

número ideal de integrantes necesarios para el proceso de adquisición de datos es de 4.

### 2.4. Procesamiento geométrico en tiempo real

Para efectos de entendimiento de esta sección, se utilizará el formato variable para referirse a

variables del código implementado en la Raspberry.

### 2.4.1. Filtrado y preprocesamiento de escaneos

Cada vuelta del LiDAR contiene un número variable de puntos, con posibles lecturas inválidas y un

espaciado irregular de los ángulos, lo que dificulta entregar una entrada fija para la red neuronal.

Para solucionar lo anterior, se implementa una función que estandariza el escaneo a un vector fijo

de 450 distancias, correspondientes a ángulos uniformemente espaciados cada 0,8 entre 0 y 359,2.

El proceso que realiza la función en el código que estandariza las mediciones del LiDAR se puede

resumir en los siguientes pasos:

1. Se filtran los puntos con distancia igual a cero, que corresponden a retornos inválidos del

sensor.

2. Los puntos restantes se ordenan por ángulo.
3. Se aplica interpolación lineal circular sobre los ángulos objetivo.
4. Se identifican espacios faltantes angulares superiores a 5 (secciones con datos faltantes). Los

ángulos del vector fijo que caen dentro de los espacios faltantes se les asigna la distancia

máxima del sensor (12.000 mm), evitando que la interpolación genere valores en zonas donde

el LiDAR no obtuvo datos en la realidad.

### 2.4.2. Detección y estimación de inclinación de rampas y del plano de suelo

La detección de superficies inclinadas es realizada por la red neuronal a partir de los datos estan-

darizados y corregidos por IMU del LiDAR. Las salidas binarias sup frontal y sup trasera de

la red indican la presencia o no de una superficie frontal o trasera al escaneo, respectivamente. En

caso de que efectivamente hayan superficies en el sector frontal o trasero del escaneo, las variables

ang sup frontal y ang sup trasera estiman el ángulo de inclinación de la superficie en grados,

con un rango de cobertura de ±15. Cabe destacar que las superficies consideran las rampas (angulo

distinto de 0°) y piso plano (ángulo 0°)

### 2.4.3. Detección y estimación de altura de escalones

De forma análoga a la detección de rampas (superficies), las salidas binarias esc frontal y esc -

trasera de la red clasifican la presencia de un escalón de forma frontal o trasera, de acuerdo a lo

mencionado. Gracias a esto se puede clasificar si la prótesis se encuentra al inicio de una escalera, a la mitad de ella o al final. La salida de la red altura escalones estima la altura del escalón en

centímetros, con un rango de cobertura de 0 a 30 cm.

### 2.4.4. Detección de obstáculos frontales en rango 0.3–3.0 m

La salida obstaculo de la red clasifica la presencia de un obstáculo al frente del usuario de la

prótesis. En caso de que se detecte uno, la salida dist obstaculo entrega una estimación de la

distancia en metros, dentro del rango de 0,3 a 3,0 m.

### 2.5. Validación de latencia extremo a extremo menor o igual a 200

ms

Para medir la latencia de extremo a extremo se usó la librería Time y se midió el tiempo en el while

loop. Naturalmente el Lidar midió a 10Hz → 100ms porque es la velocidad del mismo para captar

el ambiente, mientras que el resto del código, incluyendo la red, tardó 0.023s. Con esto, tenemos

que la latencia de extremo a extremo es de 123 ms. Lo cual cumple con el requisito pedido.

Figura 20: Latencia

### 2.6. Métricas de error y matriz de confusión

Ambas redes descritas en 16 y 17 fueron entrenadas con los datos descritos anteriormente durante

100 épocas. Se dividieron todos los datos considerando 80 % para entrenar, 20 % para validar y

testear respectivamente. Los resultados de entrenamiento son los siguientes:

Metrica/Red | Train Loss | Val Loss | Test-Acc
Red iteración 1 | 0.048 | 0.0167 | 99.58 %
Red iteración 2 | 0.024 | 0.0247 | 99.62 %

Tabla 6: Métricas de error para 100 épocas de entrenamiento

Como se puede apreciar, el error de validación más bajo viene de las muestras con IMU incluido.

Cuando una red presenta menos Loss con datos de validación con respecto a los que usa para en-

trenar, significa que fue sobre entrenada, puesto que está consiguiendo un menor error con datos parecidos entre ellos versus el que consigue con un dato nuevo de entrenamiento. La red de usada en

la iteración 2 tuvo mejores resultados de entrenamiento. En general, al usar ambas redes en tiempo

real, generaron distintos tipos de problemas, los cuales se van a describir en la siguiente sección,

pero la que usó al final fue la de la segunda iteración.

Los valores de accuracy de la sección anterior fueron probados con la base de datos separada para

test. También se generó la matriz de confusión sobre los datos binarios, es decir, evalúa qué tan bien

reconoce un objeto. En general hay mucha combinación de datos binarios los cuales son descritos

en la tabla ??, por lo que se decidió por simplicidad, juntar todos los valores que debieron ser cero

y el complemento y evaluar en cuántos efectivamente sacó el valor correcto. Los resultados son los

siguientes:

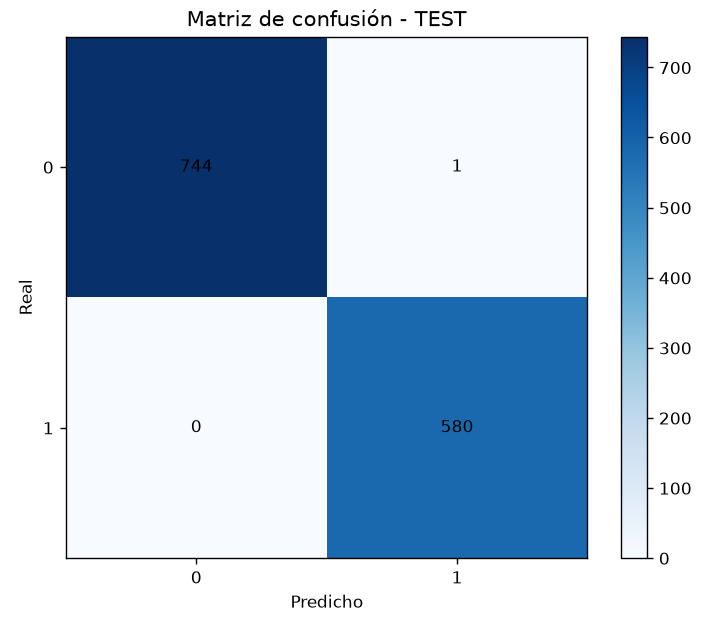
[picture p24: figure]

Figura 21: Matriz de confusión sobre Test-dataset para datos binarios

Tal como se espera del accuracy, hubo un solo falso uno, con todas estas métricas se esperaba un

correcto funcionamiento de la red en tiempo real.

### 2.7. Validación experimental en entorno controlado con medición

### de errores geométricos

De la misma manera que se muestra en la figura [19] se probó la red neuronal tanto de la primera,

como la segunda iteración. La primera de todas, saturaba todo tipo de objeto y obstáculo en

escaleras. Por otra parte, la segunda red, reconocía sin errores los objetos y lograba medir con

cierto error el ángulo de las rampas, altura de escalones y distancia a objetos. Sin embargo la red

tuvo limitaciones:

Funciona según lo esperado en entornos abiertos

En entornos cerrados los obstaculos los reconoce como escalera

En las rampas tiene un error de ±1.5

◦
, menor al solicitado de dos grados

En obstáculos el error es de ±3cm para distancias cercanas, menores a 2 metros. A distancias

supeiores el error aumenta considerablemente

Es muy sensible a movimiento, si el Lidar se mueve, las predicciones empeoran hasta que se

estabilice.

Dentro de todas estas limitantes, las causas son claras. La toma de datos. Si bien, esta fue estricta

en el etiquetado, solo se tomaron muestras en entornos abiertos, las muestras no se tomaron en

movimiento, puesto que es complejo medir la distancia de forma dinámica para etiquetar esta

misma. La falta de movimiento al tomar datos, y no tener muestras en entornos cerrados, hizo que

la red solo supiera de entornos muy controlados. Con esto, podemos concluir que sí es posible darle

visión a la prótesis, con un tiempo menor a 200ms, siendo capaz de reconocer el entorno.

Por otra parte, como trabajo futuro, hay que generar una base de datos en movimiento y predecir

solo el objeto. La distancia por su parte, es mejor calcularla con los mismos datos del Lidar, con esto

delegamos a la red la interpretación de objetos lo cual es de alta complejidad computacional, y esta

es muy eficiente en realizar este trabajo. Una vez identificado el objeto, se calculan las distancias

matemáticamente para asegurar un error mínimo (el del mismo Lidar) al momento de entregar

datos geométricos.

### 2.8. Repositorio GitHub documentado

Toda la documentación relativa al proyecto, junto con los archivos de código, modelado 3D, entregas

y otros se encuentran en el siguiente link a un repositorio público de GitHub.

Link: https://github.com/NaBo04/Lidar2D-prediction-on-prosthetic-legs

### 2.9. Manual técnico de integración, arquitectura y pruebas

Respecto a la integración física del contenedor con los demás componentes, este debe acoplarse a

la carcasa actual de la prótesis, la cual alberga las PCB existentes y la Raspberry Pi 5, fijándose

mediante tornillos ubicados en las partes superior e inferior. Asimismo, se debe garantizar que el

ángulo cero del LIDAR quede orientado hacia el frente, para asegurar su correcto funcionamiento.

Continuando con las conexiones, se encuentra la alimentación del LIDAR, la cual debe conectarse a

una fuente de 12V, ya que este cuenta con regulación interna a 5V. Además, está la conexión USB:

en un extremo debe conectarse a la Raspberry Pi 5, mientras que el extremo USB-C debe conectarse

al adaptador USB incluido en el contenedor. Por parte del IMU, se debe asegurar la alimentación

de 3.3V y su tierra correspondiente, además de las conexiones SDA y SCL, las cuales corresponden

a los pines GPIO2 y GPIO3, respectivamente.

Finalmente, respecto a la implementación de software, se deben descargar los archivos directamente

desde el repositorio de GitHub e incluirlos en un mismo directorio, el cual debe contener tres archivos

de Python, el modelo de la red neuronal y la carpeta correspondiente al environment.

Para su uso, se debe abrir la terminal de la Raspberry Pi 5 y, ubicado en el directorio de descarga,

activar el environment mediante el comando ”source env/bin/activate”. Esto permitirá cargar las

librerías específicas requeridas por el proyecto. A continuación, se debe ejecutar el comando ”python

script red IMU LIDAR.py”para iniciar el proceso de inferencia.

### 2.10. Presupuesto final

A continuación, se detallan las compras realizadas para llevar a cabo el proyecto.

Descripción | Precio | Comentarios/Justificación
Banda compresora muslera | $8.290 | Soporte para pruebas: en esta banda se montará el sistema del LiDAR para realizar pruebas previas a la propuesta de instalación del sensor en la prótesis.
Bateria | $11.000 | Soporte para pruebas: se utilizará para alimentar el sistema (5000 mAh).
Velcro Autoadhesivo | $7.480 | Soporte para pruebas: se utilizará pa- ra poder remover y ubicar fácilmente la batería en la banda utilizada. Se pe- gará una banda de velcro a la batería que usaremos para alimentar el sistema con el objetivo de que sea más simple cargarla.
Pack de pernos y tuercas | $1.490 | Para unir las piezas de impresión 3D
Filamento impresión 3D (2 kg) | $28.000 | Soporte para pruebas: se necesita im- primir el soporte donde montaremos el LiDAR y demás componentes del siste- ma junto al agarre a la banda.
IMU | $31.878 | Implementación: se utilizará para de- terminar el ángulo de inclinación de la pierna en tiempo real. Comentario: no se encontró un proveedor local confia- ble y a un precio razonable.
MCI Proto-Pi Shield de Prototipaje | $3.290 | Solicitado por la contraparte para ma- yor modulación en la aplicación.
| | Continúa en la siguiente página...

Tabla 7 – Continuación de la página anterior

Descripción | Precio | Comentarios/Justificación
Cable | Dupont | Hembra

Hembra 10cm

$1.990 Para conectar la IMU con la Raspberry

PI.

Inclinómetro nivel digital | $33.706 | Permite aislar la linea de comunicación

entre LIDAR 2D y Raspberry Pi 5.

2 Multiplexor | $8.546 | Controlar el uso de Comunicación I2C.
3 Módulo Regulador | $6.264 | Permite reducir voltaje de 5V a 3.3V.

Conversor DC-DC de 12-5

V aislado HiLink 5 W

$10.546 Alimentación aislada LIDAR 2D.

Módulo aislador digital de

doble canal ADUM1201

| $1.083 | Para realizar mediciones confiables y precisas de niveles de inclinación para validar las pruebas y resultados.
Huincha | $4.390 | Para medir la distancia real entre el Li- DAR y los obstáculos en la fase de toma de muestras.
Kit 120 Espaciadores | $6.000 | Para espaciar y fijar las PCB del sopor- te de la prótesis.
Total | $163.953

Tabla 7: Presupuesto Hito 2.

## 3. Anexo

Listing 1: Código completo

1 | # Esto c d i g o consiste en una estructura de dos procesos
2 | # En un nucleo se ejecuta el LiDAR y el IMU , y en otro n c l e o se
| procesan los datos , con la
3 | # posterior inferencia de la red neuronal . La c o m u n i c a c i n entre
| procesos se realiza mediante
4 | # una cola de multiprocessing .

5

6

7 | from servidor_web import lanzar_servidor_web # libreria que contiene
| la f u n c i n para lanzar el servidor web en un hilo separado

8

9 | import multiprocessing
10 | import threading
11 | import time
12 | import os
13 | import board
14 | import busio
15 | from pyrplidar import PyRPlidar
16 | from adafruit_bno08x import (
17 | BNO_REPORT_ACCELEROMETER ,
18 | BNO_REPORT_GYROSCOPE ,
19 | BNO_REPORT_GRAVITY
20 | )
21 | from adafruit_bno08x . i2c import BNO08X_I2C
22 | from collections import deque
23 | import numpy as np
24 | from LidarRed import LidarCNN
25 | import torch
26 | import torch . nn as nn

27

28

29 | # ==========================================
30 | # CONFIGURACIONES
31 | # ==========================================

32

33 | NUM_POINTS = 450
34 | ANGLE_STEP = 0.8
35 | MAX_RANGE_MM = 12000
36 | MAX_GAP_DEG = 5

37

38 | # | ngulos | objetivo fijos : 0.0 , 0.8 , 1.6 , ... siempre los mismos .
39 | TARGET_ANGLES = np . arange ( NUM_POINTS ) * ANGLE_STEP

40

41 | # ==========================================
42 | # FUNCIONES UTILIZADAS
43 | # ==========================================

44

45 | # Funcion de i n t e r p o l a c i n de vuelta del LiDAR
46 | # Recibe una vuelta completa de datos ( lista de tuplas ) y devuelve
| un vector fijo de 450 distancias .
47 | def interpolar_vuelta ( vuelta ) :
48 | """ Vector ␣ fijo ␣de␣450 ␣ distancias .␣ Interpola ␣con␣ puntos ␣ v l i d o s ;
| ␣ huecos
49 | ␣␣␣␣ grandes ␣( >␣ MAX_GAP_DEG )␣se␣ asignan ␣a␣ MAX_RANGE_MM ␣(sin␣ retorno ␣/
| ␣ lejano )."""
50 | angles = np . array ([ p [0] for p in vuelta ] , dtype = float )
51 | distances = np . array ([ p [1] for p in vuelta ] , dtype = float )

52

53 | valido = distances > 0.0
54 | ang_v = angles [ valido ]
55 | dist_v = distances [ valido ]

56

57 | if ang_v . size < 2:
58 | return np . full ( NUM_POINTS , MAX_RANGE_MM )

59

60 | orden = np . argsort ( ang_v )
61 | ang_v = ang_v [ orden ]
62 | dist_v = dist_v [ orden ]

63

64 | dist_interp = np . interp ( TARGET_ANGLES , ang_v , dist_v , period
| =360)

65

66 | # Huecos grandes en la cobertura v l i d a -> rango m x i m o .
67 | ext = np . concatenate ([ ang_v , [ ang_v [0] + 360.0]])
68 | for i in range ( ang_v . size ) :
69 | lo , hi = ext [ i ] , ext [ i + 1]
70 | if hi - lo > MAX_GAP_DEG :
71 | dentro = (( TARGET_ANGLES > lo ) & ( TARGET_ANGLES < hi ) ) |

(

72 | ( TARGET_ANGLES + 360.0 > lo ) & ( TARGET_ANGLES +
| 360.0 < hi )
73 | )
74 | dist_interp [ dentro ] = MAX_RANGE_MM

75

76 | return dist_interp

77

78 | def compensar_2d ( vuelta_completa , imu_capturado ) :
79 | """
80 | ␣␣␣␣ Desfasa ␣los ␣ ngulos ␣ crudos ␣del␣ LiDAR ␣ utilizando ␣el␣ vector ␣de␣
| gravedad ␣del␣IMU.
81 | ␣␣␣␣ Retorna ␣la␣ lista ␣de␣ puntos ␣ rotada ␣y␣ nivelada ␣al␣ horizonte ␣ real .
82 | ␣␣␣␣"""
83 | # 1. Extraemos la gravedad promediada

84 | grav_x , grav_y , grav_z = imu_capturado [’ grav_promedio ’]

85

86 | # 2. Calculamos el | ngulo | actual de la gravedad (en grados )
87 | # Estando nivelado : G_x = 0 , G_y = -9.8 --> angulo = -90 grados
88 | angulo_gravedad_rad = np . arctan2 ( grav_y , grav_x )
89 | angulo_gravedad_deg = np . degrees ( angulo_gravedad_rad )

90

91 | # 3. Calculamos la d e s v i a c i n respecto al ideal ( -90)
92 | desfase = angulo_gravedad_deg - 90.0

93

94 | # 4. Aplicamos el desfase angular a cada tupla
95 | vuelta_corregida = []
96 | for angulo , distancia , calidad in vuelta_completa :
97 | angulo_nuevo = ( angulo + desfase ) % 360.0
98 | vuelta_corregida . append (( angulo_nuevo , distancia , calidad ) )

99

100 | return vuelta_corregida

101

102

103 | def calcular_roll_pitch ( grav_x , grav_y , grav_z ) :
104 | """
105 | ␣␣␣␣ Calcula ␣ roll ␣y␣ pitch ␣(en␣ grados )␣a␣ partir ␣del␣ vector ␣de␣ gravedad

␣ promediado .

106 ␣␣␣␣ C o n v e n c i n ␣ e s t n d a r ␣( aeroespacial ),␣ asumiendo ␣el␣eje␣Z␣del␣

sensor ␣" hacia arriba ":

107 | ␣␣␣␣␣␣␣␣ roll ␣␣=␣ atan2 (grav_y ,␣ grav_z )
108 | ␣␣␣␣␣␣␣␣ pitch ␣=␣ atan2 ( -grav_x ,␣ sqrt ( grav_y ^2␣+␣ grav_z ^2))
109 | ␣␣␣␣ NOTA :␣si␣la␣ o r i e n t a c i n ␣ f s i c a ␣de␣ montaje ␣del␣ BNO085 ␣es␣

distinta ,␣los ␣ signos ␣o

110 | ␣␣␣␣los ␣ ejes ␣ usados ␣ a q u ␣ pueden ␣ necesitar ␣ ajuste .
111 | ␣␣␣␣"""
112 | roll_rad | = np . arctan2 ( grav_y , grav_z )

113 | pitch_rad = np . arctan2 ( - grav_x , np . sqrt ( grav_y **2 + grav_z **2) )
114 | return np . degrees ( roll_rad ) , np . degrees ( pitch_rad )

115

116

117 | def load_model ( device , pesos_path =’ lidar_cnn_model .pth ’) :
118 | model = LidarCNN () . to ( device )
119 | if os . path . exists ( pesos_path ) :
120 | model . load_state_dict ( torch . load ( pesos_path , map_location =
| device ) )
121 | print ( f" Modelo ␣ cargado ␣ desde :␣{ pesos_path }")
122 | else :
123 | print ( f"No␣se␣ e n c o n t r ␣ ’{ pesos_path } ’.␣Se␣ u s a r ␣un␣ modelo ␣
| con␣ pesos ␣ aleatorios .")
124 | model . eval ()
125 | return model

126

127

128 | def normalizar_datos ( X_lidar , X_imu ) :
129 | X_lidar_min = X_lidar .min( dim =1 , keepdim = True ) [0]
130 | X_lidar_max = X_lidar .max( dim =1 , keepdim = True ) [0]
131 | X_lidar_norm = ( X_lidar - X_lidar_min ) / ( X_lidar_max -
| X_lidar_min + 1e -8)

132

133 | X_imu_mean = X_imu . mean ( dim =1 , keepdim = True )
134 | X_imu_std = X_imu . std ( dim =1 , keepdim = True )
135 | X_imu_norm = ( X_imu - X_imu_mean ) / ( X_imu_std + 1e -8)

136

137 | return X_lidar_norm , X_imu_norm

138

139 | def normalizar_lidar ( X_lidar ) :
140 | """
141 | ␣␣␣␣ X_lidar :␣ tensor ␣de␣ forma ␣(B,␣N)␣o␣(N ,).

142 ␣␣␣␣ Normaliza ␣ cada ␣ fila ␣ usando ␣su␣ propio ␣min/max␣( independiente ␣

entre ␣ filas ).

143 | ␣␣␣␣"""
144 | X_lidar = X_lidar . float ()
145 | if X_lidar . dim () == 1:
146 | X_lidar = X_lidar . unsqueeze (0) | # (N ,) -> (1 , N)

147

148 | X_lidar_min = X_lidar .min( dim =1 , keepdim = True ) [0]
149 | X_lidar_max = X_lidar .max( dim =1 , keepdim = True ) [0]
150 | X_lidar_norm = ( X_lidar - X_lidar_min ) / ( X_lidar_max -
| X_lidar_min + 1e -8)

151

152 | return X_lidar_norm . float ()

153

154 | def normalizar_datos ( X_imu ) :
155 | X_imu = X_imu . float ()
156 | if X_imu . dim () == 1:
157 | X_imu = X_imu . unsqueeze (0)
158 | X_imu_mean = X_imu . mean ( dim =1 , keepdim = True ) [0]
159 | X_imu_std = X_imu . std ( dim =1 , keepdim = True ) [0]
160 | X_imu_norm = ( X_imu - X_imu_mean ) / ( X_imu_std + 1e -8)
161 | return X_imu_norm . float ()

162

163

164 | # ==========================================
165 | # BUFFERS PARA LA MEDIA M V I L
166 | # ==========================================
167 | # G u a r d a r n exactamente las | ltimas | 10 muestras
168 | historial_grav_x = deque ( maxlen =10)
169 | historial_grav_y = deque ( maxlen =10)
170 | historial_grav_z = deque ( maxlen =10)

171

172 | # ==========================================
173 | # VARIABLE COMPARTIDA ( Memoria del Productor )
174 | # ==========================================
175 | # Inicializamos con valores neutros ( gravedad apuntando hacia abajo

en Y por defecto )

176 # (SE PUEDEN CAMBIAR EL MODO EN EL QUE SE ALMCENA LOS DATOS SI SE

DESEA )

177 | datos_imu_actuales = {
178 | ’accel ’: (0.0 , 0.0 , 0.0) ,
179 | ’gyro ’: | (0.0 , 0.0 , 0.0) ,
180 | ’ grav_promedio ’: | (0.0 , -9.8 , 0.0)
181 | }

182

183 | # ==========================================
184 | # HILO SECUNDARIO (Lee el IMU a 100 Hz)
185 | # ==========================================
186 | def lector_imu_hilo () :
187 | global datos_imu_actuales

188

189 | try :
190 | # 1. I n i c i a l i z a c i n del bus I2C y el sensor
191 | i2c = busio . I2C ( board . SCL , board . SDA )
192 | bno = BNO08X_I2C ( i2c )

193

194 | # 2. H a b i l i t a c i n de los 3 reportes solicitados
195 | bno . enable_feature ( BNO_REPORT_ACCELEROMETER )
196 | bno . enable_feature ( BNO_REPORT_GYROSCOPE )
197 | bno . enable_feature ( BNO_REPORT_GRAVITY )

198

199 | # Pre - llenamos el buffer para que los primeros 100 ms no
| promedien con ceros
200 | for _ in range (10) :

201 | historial_grav_x . append (0.0)
202 | historial_grav_y . append ( -9.8)
203 | historial_grav_z . append (0.0)

204

205 | print ("[IMU ]␣ BNO085 ␣ inicializado .␣ Leyendo ␣Accel ,␣ Gyro ␣y␣
| Gravedad ␣a␣100 Hz.")

206

207 | except Exception as e :
208 | print ( f"[ ERROR ␣IMU]␣No␣se␣ pudo ␣ inicializar ␣el␣ sensor .␣ Revisa
| ␣I2C.␣ Detalle :␣{e}")
209 | return # Termina el hilo de forma segura si no hay hardware

210

211 | # 3. Bucle infinito de lectura
212 | while True :
213 | try :
214 | # Extraemos las tuplas (x, y, z) directamente del
| hardware
215 | accel_x , accel_y , accel_z = bno . acceleration
216 | gyro_x , gyro_y , gyro_z = bno . gyro
217 | grav_x , grav_y , grav_z = bno . gravity

218

219 | # Agregamos la nueva lectura al historial ( empuja y
| borra la m s vieja )
220 | historial_grav_x . append ( grav_x )
221 | historial_grav_y . append ( grav_y )
222 | historial_grav_z . append ( grav_z )

223

224 | # Calculamos el promedio de los | ltimos | 10 datos (
| aplasta el ruido )
225 | prom_x = sum ( historial_grav_x ) / 10.0
226 | prom_y = sum ( historial_grav_y ) / 10.0
227 | prom_z = sum ( historial_grav_z ) / 10.0

228

229 | # Actualizamos el DICCIONARIO GLOBAL (SE PUEDEN CAMBIAR

EL MODO EN EL QUE SE ALMCENA LOS DATOS SI SE DESEA )

230 | datos_imu_actuales = {
231 | ’accel ’: ( accel_x , accel_y , accel_z ) ,
232 | ’gyro ’: | ( gyro_x , gyro_y , gyro_z ) ,
233 | ’ grav_promedio ’: | ( prom_x , prom_y , prom_z )
234 | }

235

236 | # Retardo exacto para mantener la frecuencia de 100 Hz
| (10 ms)
237 | time . sleep (0.01)

238

239 | except OSError :
240 | # Los buses I2C a veces tienen micro - desconexiones
| f s i c a s .
241 | # Capturamos el error silenciosamente para que el hilo
| no muera
242 | # y reintente en el siguiente ciclo .
243 | pass

244

245 | # ==========================================
246 | # PROCESO 1: SUPER PRODUCTOR ( Anclado al N c l e o 1)
247 | # ==========================================
248 | def productor_sensores ( cola_datos ) :
249 | os . sched_setaffinity (0 , {1})

250

251 | # Arrancamos el Hilo del IMU en el fondo
252 | hilo_imu = threading . Thread ( target = lector_imu_hilo , daemon = True )
253 | hilo_imu . start ()

254

255 | # Inicializamos el LiDAR

256 | lidar = PyRPlidar ()
257 | lidar . connect ( port ="/dev/ ttyUSB0 ", baudrate =460800 , timeout =3)

258

259 | # LIMPIEZA DE BUFFER ( Crucial para reiniciar sin errores )
260 | lidar . stop ()
261 | time . sleep (0.2)
262 | lidar . lidar_serial . _serial . reset_input_buffer ()
263 | lidar . lidar_serial . _serial . reset_output_buffer ()
264 | time . sleep (0.3)

265

266 | lidar . set_motor_pwm (500)
267 | time . sleep (2) # Esperamos a que el motor alcance velocidad
| estable

268

269 | scan_generator_func = lidar . start_scan ()

270

271 | # | OPTIMIZACIN | SUPREMA !: Instanciamos el iterador de flujo

c o n t n u o una sola vez afuera

272 | generador = scan_generator_func ()

273

274 | # Enganchamos el flujo buscando el PRIMER inicio oficial antes
| de entrar al while
275 | proximo_inicio = None
276 | for scan in generador :
277 | if scan . start_flag :
278 | proximo_inicio = scan
279 | break

280

281 | print ("[ SISTEMA ]␣ Iniciando ␣ r e c o l e c c i n ␣ sincronizada ␣ LiDAR ␣+␣IMU
| ␣( Inline ␣ Stream )...")

282

283 | # 3. Bucle principal unificado ( Todo en una sola estructura

lineal )

284 | while True :
285 | try :
286 | # Inicializamos la lista directamente con el punto que
c e r r | la vuelta anterior
287 | # A s | no perdemos muestras y mantenemos el desfase de

hardware controlado

288 | vuelta_completa = [( proximo_inicio . angle , proximo_inicio

. distance , proximo_inicio . quality ) ]

289

290 | # R E C O L E C C I N PURA EN UN SOLO BUCLE EN L N E A
291 | for scan in generador :
292 | if scan . start_flag :
293 | # Capturamos el inicio de la SIGUIENTE vuelta y
| rompemos el bucle actual
294 | proximo_inicio = scan
295 | break
296 | # Guardamos los puntos intermedios a velocidad
| nativa de C
297 | vuelta_completa . append (( scan . angle , scan . distance ,
| scan . quality ) )

298

299 | # Ordenamos los puntos por | ngulo | ( vital para

interpolar_vuelta en el N c l e o 2)

300 | vuelta_completa . sort ( key = lambda p : p [0])

301

302 | # Capturamos la foto exacta del IMU promediado en este
| instante de cierre
303 | imu_capturado = datos_imu_actuales . copy ()

304

305 | # Enviamos el paquete combinado al Cerebro

306 | paquete = ( vuelta_completa , imu_capturado )
307 | cola_datos . put_nowait ( paquete )

308

309 | except multiprocessing . queues . Full :
310 | # Si el Cerebro se satura , saltamos el paquete para
| proteger los tiempos reales
311 | pass
312 | except KeyboardInterrupt :
313 | break

314

315 | # Apagado seguro
316 | lidar . stop ()
317 | lidar . set_motor_pwm (0)
318 | lidar . disconnect ()

319

320

321 | # ==========================================
322 | # PROCESO 2: EL CEREBRO ( Anclado al N c l e o 2)
323 | # ==========================================
324 | def consumidor_datos ( cola_datos , cola_web ) :
325 | os . sched_setaffinity (0 , {2})

326

327 | # cargar modelo ( antes del while )
328 | modelo = load_model ( device =’cpu ’, pesos_path =’ lidar_cnn_model .
| pth ’)
329 | contador = 0

330

331 | while True :
332 | # Esperamos y desempaquetamos los datos
333 | paquete = cola_datos . get ()
334 | vuelta_completa , imu_capturado = paquete

335

336 | # N I V E L A C I N : Corregimos los | ngulos | con la gravedad del
| IMU
337 | vuelta_nivelada = compensar_2d ( vuelta_completa ,
| imu_capturado )

338

339 | # I N T E R P O L A C I N : Forzamos los puntos al vector fijo de 450

elementos

340 | # - vuelta_interpolada_cruda : | LiDAR crudo (sin nivelar

por IMU), interpolado

341 | # - vuelta_interpolada_nivelada : LiDAR nivelado por IMU ,

interpolado

342 | vuelta_interpolada_cruda | = interpolar_vuelta (

vuelta_completa )

343 | vuelta_interpolada_nivelada = interpolar_vuelta (

vuelta_nivelada )

344

345 | # ROLL / PITCH : derivados del vector de gravedad promediado
346 | accel_x , accel_y , accel_z = imu_capturado [’accel ’]
347 | grav_x , grav_y , grav_z = imu_capturado [’ grav_promedio ’]
348 | roll_deg , pitch_deg = calcular_roll_pitch ( grav_x , grav_y ,
| grav_z )

349

350 | # La inferencia recibe un vector de 450 distancias crudos

interpolados mas 8 datos del imu (sin giroscopio ) y

devuelve un diccionario con la p r e d i c c i n

351 | X_lidar = torch . from_numpy ( vuelta_interpolada_nivelada .
| astype (’float32 ’) ) . unsqueeze (0) | # (1 , 450)
352 | X_imu = torch . from_numpy ( np . array ([
353 | accel_x , accel_y , accel_z , grav_x , grav_y , grav_z ,
| roll_deg , pitch_deg
354 | ] , dtype = np . float32 ) ) . unsqueeze (0) | # (1 , 8)

355

356 | # Normalizamos los datos de entrada
357 | X_lidar_norm = normalizar_lidar ( X_lidar )
358 | X_imu_norm = normalizar_datos ( X_imu )

359

360 | # Inferencia con el modelo
361 | with torch . no_grad () :
362 | salida = modelo ( X_lidar_norm ) . squeeze (0)
363 | prediccion = salida . cpu () . numpy () | # Convertimos a numpy

para enviar al web [9 ETIQUETAS { sup_frontal ,

sup_trasera , esc_frontal , esc_trasera , obstaculo ,

ang_sup_frontal , ang_sup_trasera , altura_escalones ,

| dist_obstaculo }]

364

365 | prob_binarias = torch . sigmoid ( salida [:5]) . cpu () . numpy ()
366 | valores_regresion = torch . sigmoid ( salida [5:]) . cpu () . numpy ()
367 | pred_binarias = ( prob_binarias > 0.5) . astype (int)

368

369 | nombres_etiquetas = [
370 | " sup_frontal ␣(bin )", " sup_trasera ␣(bin)", " esc_frontal ␣(
| bin)",
371 | " esc_trasera ␣(bin )", " obstaculo ␣(bin)", " ang_sup_frontal
| ␣( float )",
372 | " ang_sup_trasera ␣( float )", " altura_escalones ␣( float )", "
| dist_obstaculo ␣( float )"
373 | ]

374

375 | if contador == 15:
376 | print ( f"\n=== ␣ INFERENCIA ␣ RANDOM ␣EN␣ V A L I D A C I N ␣===")
377 | for i , nombre in enumerate ( nombres_etiquetas [:5]) :
378 | print ( f"{ nombre }:␣ pred ={ pred_binarias [i]}␣( prob ={
| prob_binarias [i ]:.4 f})")

379 | for i , nombre in enumerate ( nombres_etiquetas [5:] , start
| =5) :
380 | if nombre == " ang_sup_frontal ␣( float )" or nombre ==
| " ang_sup_trasera ␣( float )":
381 | print ( f"{ nombre }:␣ pred ={( valores_regresion [i
| -5]*30 -15) :.4f}")
382 | if nombre == " dist_obstaculo ␣( float )":
383 | print ( f"{ nombre }:␣ pred ={( valores_regresion [i
| -5]*2.7+0.3) :.4 f}")
384 | if nombre == " altura_escalones ␣( float )":
385 | print ( f"{ nombre }:␣ pred ={( valores_regresion [i
| -5]*30) :.4 f}")
386 | print (" ============================================\ n")
387 | contador = 0

388

389 | contador += 1

390

391 | # 4. E X P O R T A C I N WEB ( Todo el paquete en un diccionario de
| una l n e a )
392 | try :
393 | cola_web . put_nowait ({
394 | " cruda ": vuelta_completa ,
395 | " nivelada ": vuelta_nivelada ,
396 | " interpolada_cruda ": vuelta_interpolada_cruda . tolist

() ,

397 | " interpolada ": vuelta_interpolada_nivelada . tolist () ,
398 | "imu ": imu_capturado ,
399 | " imu_roll_deg ": roll_deg ,
400 | " imu_pitch_deg ": pitch_deg
401 | })
402 | except multiprocessing . queues . Full : pass

403

404

405

406 | # ==========================================
407 | # ARRANQUE PRINCIPAL DEL PROGRAMA
408 | # ==========================================
409 | if __name__ == ’__main__ ’:
410 | # 1. D e f i n i c i n de las colas
411 | cola_compartida = multiprocessing . Queue ( maxsize =3)
412 | cola_web = multiprocessing . Queue ( maxsize =1)

413

414 | # 2. C r e a c i n de los procesos
415 | proceso_web = multiprocessing . Process ( target = lanzar_servidor_web
| , args =( cola_web ,) )
416 | proceso_sensores = multiprocessing . Process ( target =
| productor_sensores , args =( cola_compartida ,) )

417

418 | # Se inyectan AMBAS colas al cerebro
419 | proceso_cerebro = multiprocessing . Process ( target =
| consumidor_datos , args =( cola_compartida , cola_web ) )

420

421 | try :
422 | # 3. Arranque de los procesos
423 | proceso_web . start ()
424 | proceso_cerebro . start ()
425 | proceso_sensores . start ()

426

427 | # 4. Mantener vivo el script principal
428 | proceso_sensores . join ()
429 | proceso_cerebro . join ()
430 | proceso_web . join ()

431

432 | except KeyboardInterrupt :

433 | print ("\n[ SISTEMA ]␣ Deteniendo ␣ procesos ␣de␣ forma ␣ segura ...")
434 | proceso_sensores . terminate ()
435 | proceso_cerebro . terminate ()
436 | proceso_web . terminate ()

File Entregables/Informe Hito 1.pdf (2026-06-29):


### PONTIFICIA UNIVERSIDAD CATOLICA DE CHILE ´

### ESCUELA DE INGENIERÍA

### DEPARTAMENTO DE INGENIERÍA ELECTRICA ´

# Hito 1: Propuesta Conceptual y

# Diseño Funcional

PROYECTO DE TÍTULO - IEE3112

Profesor: Felipe Nuñez

Grupo 2

25 de mayo de 2026

## Índice

1 Arquitectura general del sistema | 2
2 Definición de bloques funcionales | 5

2.4 Plataforma de procesamiento embebido (Raspberry Pi 5 o actualización a re-

3 Especificación y definición de componentes | 11
4 Procesamiento y clasificación de datos | 12
5 Diseño del soporte mecánico | 14
6 Presupuesto inicial | 16

## 1. Arquitectura general del sistema

La siguiente figura muestra el diagrama de bloques de alto nivel, el cuál entrega una primera

idea simplificada de cuál es el flujo del sistema en su totalidad. A modo de explicación, el

sistema inicia con un bloque de sensores que miden el entorno, los cuáles entregan medidas a la

Raspberry Pi 5. Esta se encarga del procesamiento de las medidas, la predicción mediante uso

de algoritmos de Machine Learning y la posterior comunicación para validación del usuario

monitor. El objetivo es que las predicciones sirvan para ejecutar una reacción por parte de

la prótesis, aunque se escapa de los objetivos de este proyecto. Finalmente, el sistema posee

su sub-sistema de alimentación, que le otorga independencia.


Figura 1: Diagrama de Bloques de Alto Nivel

Como se puede observar en la figura, los bloques siguen cierto código de colores, el cuál se

detalla en la leyenda a continuación.


Figura 2: Leyenda

Una vez entendido el sistema de manera general, se puede proceder a analizar el diagrama de bloques de bajo nivel. El cual, es escala macro, se ve como sigue. Luego, se detallará cada

sub-sistema con detenimiento.


Figura 3: Diagrama de Bloques de Bajo Nivel (Completo)

Por motivos de la baja resolución de este en el informe, se procede a analizar el diagrama

por partes.


Figura 4: Diagrama de Bloques de Bajo Nivel (Parte 1)

La primera parte de este diagrama, incluye los bloques de sensores en color celeste, alimen-

tación y considera elementos externos. Esta parte es lo que concentra la mayor parte del

Hardware del sistema. En cuanto a los sensores, se aprecian el sensor principal: el LIDAR,

la unidad de medición inercial (IMU) y sus adaptadores. Lo relacionado al LIDAR funciona mediante protocolo UART, mientras que lo relacionado al IMU usa protocolo I2C. Por otra

parte, en color rojo, se encuentra lo relacionado a la alimentación. Estos bloques aparecen

principalmente para alimentar correctamente, y sobre todo proteger el sensor LIDAR y ais-

larlo contra posibles amenazas, por su sensibilidad y costo. Se explicará más en detalle en las

secciones correspondientes. Finalmente, en color azul, se encuentran elementos externos que

ya forman parte del proyecto, pero que decidimos tomar en consideración, para una correcta

cohesión con el desarrollo del proyecto. Estas son la alimentación de las baterías actuales, la

PCB del sistema de baterías y los encoders magnéticos.


Figura 5: Diagrama de Bloques de Bajo Nivel (Parte 2)

La segunda parte de este diagrama incluye los sub-sistemas de procesamiento, predicción,

comunicación y monitoreo de usuario. La primera parte, en color verde, muestra la coordina-

ción de los 2 sistemas de adquisición de datos mediante los sensores, para formar los datos de

entrada para el modelo de red neuronal. Luego, en color morado, se encuentra lo relacionado

al algoritmo de predicción como tal, lo que incluye también la toma y guardado de datos

de forma local, para usarlos a lo largo del entrenamiento del modelo. En color amarillo, se

incluye el bloque de comunicación, que servirá durante las implementaciones finales y de-

bugueo correspondiente. Al final de la cadena, en rosado, está el bloque que corresponde al

monitoreo del sistema de forma remota, mediante una interfaz para el usuario. Por último,

en la imagen se aprecian 2 bloques de color azul, que nuevamente son funciones externas al objetivo del proyecto, relacionadas al sistema de reacción/actuación frente a la predicción.

## 2. Definición de bloques funcionales

### 2.1. Fuente de alimentación

La prótesis transfemoral activa ya cuenta con una batería integrada que alimenta la electróni-

ca de control existente. Esta misma fuente de energía será utilizada para suministrar potencia

a los nuevos subsistemas de percepción (LIDAR e IMU).

Dado que la batería ya se encuentra dimensionada y validada para la operación de la prótesis,

no es responsabilidad de este proyecto redefinir, reemplazar o caracterizar la fuente de ali-

mentación. En su lugar, nos enfocamos en asegurar que los nuevos componentes (RPLIDAR

C1 e IMU BNO085) sean compatibles con los niveles de voltaje y corriente disponibles en el

sistema existente.

La integración se realiza mediante un convertidor DC-DC aislado modelo VRB1205YMD de

12 a 5 V de 5 W, que permite adaptar la tensión de la batería a los requerimientos específicos

del LIDAR (4.8-5.2V a 260 mA típico) y para poder suministrar la corriente peak del Lidar

(1A en la partida). Este convertidor actúa como interfaz entre la fuente centralizada de la

prótesis y los nuevos sensores, protegiendo ambos subsistemas de variaciones en la tensión

de la batería. Mientras que la IMU (3-5V a 3-5 mA) se alimentará desde la misma fuente

utilizada por la Raspberry 5 Pi. Para las fases de prototipado y validación experimental, se

utilizará una batería portátil de 5000 mAh que proporciona conexión USB estándar y voltaje

de salida 5V.


Figura 6: Batería para validación experimental

### 2.2. Módulo LIDAR 2D

Para este proyecto se utilizará el modelo RPLIDAR C1, el cual tiene un rango de medición

de 12 metros para objetos claros y de 6 para oscuros. Además, presenta una frecuencia de

muestreo de 5 kHz, un campo de visión 360° y una precisión de ± 30 mm.

Utiliza un puerto TTL UART con un baud rate de 460,800 bps para proporcionar información

de distancia (mm), ángulo (grados), señal de inicio de escaneo y datos de reflectividad (2.5D).

Los requerimientos de funcionamiento son principalmente una alimentación de 5 V y 230 mA.

El dispositivo es ligero, tiene un peso aproximado de 110 g, y es resistente a polvo y salpi-

caduras. Sin embargo, se debe tener la precaución de no exponer el láser directamente al sol

puesto que podría dañar irreversiblemente su funcionamiento.

### 2.3. Aislación del Módulo LIDAR 2D

Un LiDAR 2D es un sensor electromecánico de operación continua. Por esta razón, compartir

la misma referencia de tierra con una Raspberry Pi 5 puede ocasionar diversos inconvenientes.

El primero de ellos es la inyección de ruido electromecánico. Los motores, al ser cargas

inductivas, junto con su conmutación electrónica, generan picos de voltaje que se inyectan directamente en el plano de tierra. Otro problema importante son las corrientes de irrupción

(inrush), que consisten en corrientes transitorias de arranque capaces de provocar caídas

momentáneas de tensión, comprometiendo así la estabilidad de los rieles de alimentación de

la Raspberry Pi 5.

La solución a estos problemas es la aislación galvánica del motor con el sistema de control,

tanto para proteger el LIDAR 2D como la Raspberry Pi 5. Tal como se mencionó en etapas

anteriores, se utiliza un conversor DC-DC tipo Buck conectado en el lado de alto voltaje a

12V desde la batería (ya integrada en la prótesis) y en la lado de bajo voltaje a 5V conectado

a los rieles de alimentación del LIDAR 2D.

Para mantener el aislamiento galvánico en las líneas de comunicación entre la Raspberry Pi 5

y el LiDAR 2D, se implementará el aislador digital ADuM1201. Dado que los niveles lógicos

de salida de este módulo dependen exclusivamente de las tensiones aplicadas a sus rieles de

alimentación, y considerando que tanto el LiDAR 2D como el adaptador USB operan con

lógica de 3.3 V, resulta importante el uso de dos reguladores de tensión AMS1117-3.3 para

fijar dicho voltaje en ambos extremos del circuito.

### 2.4. Plataforma de procesamiento embebido (Raspberry Pi 5 o

### actualización a reComputer J20)

### 2.5. Sistema de comunicación

Los bloques funcionales presentados previamente necesitan transmitir datos entre ellos para

un correcto funcionamiento del sistema. En general los distintos bloques comunican o reciben

datos desde la Raspberry, que actúa en este caso como nodo central del sistema. A conti-

nuación se enumeran las principales conexiones para la transmisión de datos y los protocolos

utilizados.

Conexión LiDAR → Raspberry:

La conexión entre estos dos nodos se realiza mediante protocolo UART con una conexión

micro-usb. Lo anterior se justifica debido a las especificaciones del LiDAR, ya que transmite por defecto sus datos con protocolo UART. Además, el adaptador usb del

LiDAR facilita la conexión directa con la Raspberry a través de uno de sus puertos.

El formato en que se envían los datos será la distancia de la medición del láser del

LiDAR y el ángulo de este.

Conexión IMU → Raspberry El sensor IMU se conecta con la Raspberry a través de

protocolo I2C. Se eligió este protocolo debido a que es el que tiene el sensor por defecto,

además de ser simple y robusto de implementar para esta aplicación.

Un aspecto relevante a tener en cuenta es que el sensor no se conectará directo a

terminales I2C de la Raspberry, debido a que estos están siendo utilizados por otros

sensores que son parte de la implementación de la prótesis, pero externos a este proyecto.

Debido a lo anterior, se utilizará un multiplexor I2C al que se conectará otro sensor

además del IMU, de tal forma que puedan compartir un solo puerto I2C de la raspberry.

El multiplexor a utilizar se conectará a los 3 sensores y a un solo puerto de la raspberry.

Cómo se pudo observar en el diagrama de bloques inicial, los tres sensores serían dos

encoders magnéticos y el IMU, la estrategia para que coincidan los tiempos del LiDAR

y el IMU es utilizar el Lidar a 100 Hz y el IMU a 10 Hz una vuelta completa (ambos

se pueden utilizar en estas configuraciones de muestreo).

De esta forma, el multiplexor escuchará principalmente al IMU enviando mediciones

cada 100 Hz. Luego, cada 10 Hz, se enviarán las muestras del encoder para que coincidan

con las mediciones del LiDAR, coordinandose de esta forma la utilización del puerto

I2C, las mediciones del IMU y la medición del LiDAR con sus respectivas frecuencias

de muestreo.

Los datos que se recibirán del IMU corresponden a la posición relativa del LiDAR

respecto a cierto marco de referencia. Esta medición se envía mediante quaterniones,

dado que el dispositivo utilizado tiene la capacidad de enviar sus datos directamente

en este formato.

Conexión Raspberry ↔ Interfaz de monitoreo:

El objetivo de esta conexión es enviar los datos de medición del LiDAR y el IMU, además

de las clasificaciones realizadas por el modelo de Machine Learning a una plataforma

externa donde se pueda monitorear el funcionamiento de la prótesis.

Para esta funcionalidad se transmitirán los datos vía WiFi con protocolo MQTT. La

razón de esto es que se necesita una transmisión inalámbrica de los datos, por lo que

se decidió utilizar el módulo WiFi que tiene integrado la Raspberry.

Por otro lado, se eligió el protocolo MQTT debido a las características de la aplicación,

este protocolo está pensado para dispositivos IoT donde el envío de datos se realiza

en condiciones de redes inestables y anchos de banda limitados, además permite una

lectura simple de los datos desde otros dispositivos como un ordenador o una página

web para mostrar los datos recibidos en tiempo real.

Los datos se enviarán cada vez que el modelo realice una clasificación, el formato de

envío de los datos será la clasificación con el tipo de obstáculo y características como

ángulo de inclinación en caso de una rampa y altura del escalón en caso de una escalera.

Sumado a lo anterior, se enviará en el mismo paquete las entradas del LiDAR y el IMU

con las que se realizó la clasificación.

### 2.6. Almacenamiento y monitoreo de datos

Como se observa en el diagrama de bloques de bajo nivel del sistema, los datos tienen dos

destinos, un almacenamiento en la Raspberry y un envío remoto mediante WiFi y MQTT

que fue adelantado en la sección anterior, y hacia el bloque controlador de la prótesis. En

esta sección se explicarán más a detalle ambos destinos de los datos luego de la clasificación.

Almacenamiento local: Su objetivo es almacenar únicamente las mediciones del Lidar

y el Imu para posteriormente seguir entrenando al modelo con estos datos. El almace-

namiento se realiza en una base de datos local dentro de la raspberry en su tarjeta SD,

para posteriormente cargarlos en otro dispositivo y trabajar con ellos.

Envío remoto para monitoreo: Este flujo de datos es el que se explicó en la sección

anterior. El objetivo es que cada cierto envíe las clasificaciones realizadas y los datos de entrada con los que realizó la clasificación.

Para este proyecto, estos datos serán leídos desde el Broker MQTT desde un compu-

tador que generará una interfaz gráfica local con un script en Python. El objetivo de

esto es mostrar de una forma amigable y útil para trabajar los datos en los experimentos

para testear el funcionamiento de la implementación del proyecto.

Cabe destacar que si bien la implementación de la interfaz gráfica mediante la lectura

de datos desde un computador, gracias a la arquitectura MQTT es posible también

escalar hacia una página web donde se lean los datos en tiempo real, sin embargo, esto

escapa del proyecto y se puede implementar en una etapa más avanzada de la prótesis.

Controlador: Finalmente, el controlador de la prótesis que envía la acción de control

al motor actuador, recibe únicamente la clasificación de obstáculos realizada por el

modelo, donde recibe el tipo de obstáculos y datos relevantes como la altura del escalón

si el obstáculo es una escalera, el ángulo de inclinación si es una rampa, entre otros.

Este bloque aún no está implementado y no forma parte del proyecto actual, por lo que

solo se define cómo recibirá los datos.

## 3. Especificación y definición de componentes

Componente | Modelo/Especificación | Parámetros Clave
Sensor LIDAR 2D | RPLIDAR C1 (C1M1-R2) | Alcance: 0.05–12 m Frecuencia: 10 Hz @ 600 RPM Resolución: 0.72° Precisión: ±30 mm Peso: 110 g
IMU 9-DOF | Adafruit BNO085 | Acelerómetro: ±16 g Giroscopio: ±2000°/s Magnetómetro: ±4900 µT Interfaz: I²C/UART/SPI Fusión sensorial: Cortex-M0 Voltaje entrada: 3–5 V DC Consumo: ∼3–5 mA típico Precisión angular: ±2°
Interfaz LIDAR | UART TTL 3.3V XH2.54-5P | Velocidad: 460800 bps Modo: 8n1 Tensión salida: 0–3.5 V
Procesador | Raspberry Pi 5 Model B | CPU: BCM2712 Quad-Core ARM Cortex-A76 Frecuencia: 2.40 GHz Arquitectura: 64-bit aarch64 RAM: 8 GB GPU: Broadcom VideoCore VI Sistema operativo: Debian GNU/Linux 13 (Trixie) Kernel: Linux 6.12.75+rpt-rpi-2712 Compatible con ROS 2

Tabla 1: Especificaciones de componentes para integración de LIDAR en prótesis transfemoral activa

A continuación se presenta una tabla con los consumos energéticos principales de los com-

ponentes de la implementación. El resto de componentes de este proyecto no se tomaron en

cuenta debido a que sus consumos son despreciables en relación a los que se presentarán a

continuación:

Esta tabla permite calcular la autonomía de la batería del sistema implementado en este

proyecto, así como el de la prótesis en su totalidad al considerar los consumos del resto de

Tabla 2: Tabla con principales consumos

Componente | Consumo (W)
Sensor LiDAR 2D | 1.35 W
Conversor DC-DC Aislado (pérdida por conversión) | 0.25 W
Raspberry PI | 10 W

bloques ya implementados en la prótesis.

Considerando que el power bank utilizado para las pruebas tiene una capacidad de 5000

mAh, la autonomía de la batería es de aproximadamente 2 horas y 10 minutos.

## 4. Procesamiento y clasificación de datos

Existen diversas topologías enfocadas en nubes de puntos para detectar objetos como PoinNet

o PoinNet++ las cuales usan simplemente MLP. Ahora, estas topologías simples no aprove-

chan el hecho de que el Lidar entrega los datos en forma ordenada r(θ) por lo que los modelos

propuestos usan CONV1D para aprovechar estas ventanas de datos, los cuales al ser cercanos

proporcionan cierta información que puede ser captada por un kernell de convolución. Por

otro lado no se usa CONV2D porque sería entregar la nube de puntos como una imagen, lo

cual aumenta el tiempo de procesamiento.

En base a esto, los papers siempre usan como capa base las convolucionales 1D, adoptando

diversas cantidades de neuronas, max pooling, agregando más información al input como

pueden ser los datos de un IMU, o agregando capas con memoria como RNN, GRU o STM.

Todo depende de la dificultad que se quiere conseguir como output de la red.

A continuación se presentan dos modelos, los cuales tienen diversos fines y grados de dificultad


2D LaserNet | CNN+TSM

Figura 7: Diferentes topologías ML

La primera imagen es una red muy simple, la cual transforma los datos r(θ) → (x, y) de

ahí el input NX2, cada uno de ellos se procesa con capas CONV1D por rapas separadas,

aplican max pooling para reducir dimensionalidad quedándose solo con datos importantes,

finalmente condensan todo y se procesa por la típica MLP. Esta red extrae diversas clases,

y fue creada para la detección de elementos como corredores, pasillos, piezas, puertas, entre

otras. Se consigue un accuracy superior al 95 % con excepción de las puertas. La detección

ocurre en tiempo real y puede ser usada sobre robots para el monitoreo del entorno.

La segunda imagen implementa los datos del Lidar en conjunto con el IMU, acá los datos se

procesan pasa conseguir distintos parámetros, los cuales se suman a una estimación de los

objetos cercanos y los datos del IMU dando vector de 26 entradas como input. La idea es

estimar la posición (x,y) y el radio de un objeto. Esta red es muy precisa e implementa una

capa STM para agregar memoria al sistema, de esta forma la red sabe de alguna manera que

el objeto o el robot pueden estar en movimiento y lo considera debido a que su salida no es

una simple clasificación, si no que la dimensionalidad y la posición también.

El modelo propuesto consiera el punto medio entre ambos puntos, considerando capas con-

volucionales 1D como base y probar métodos como:

Input coordenadas r(θ) con información de IMU

Input coordenadas (x, y) con información de IMU considerando procesamiento por ca-

pas separadas

Probar distintas cantidades de capas, neuronas, agregar GRU o RNN y generar un

trade off entre tiempo de procesamiento, uso de la CPU y accuracy, para saber si vale

la pena en este contexto agregar memoria a la red o no.

## 5. Diseño del soporte mecánico

Para el soporte mecánico se diseño una rampa que pudiera corregir la inclinación de la pierna

y de esta forma se orientara el laser de forma tal que este perpendicular al suelo. Para calcular

el angulo de inclinación se utilizó una foto de referencia, se dibujó un triangulo rectángulo y

se midió digitalmente los largos de sus catetos. Posteriormente, se utilizaron dichos valores y

se obtuvo un angulo de 6.12°.


Dibujo esquemático de


la pierna. | Cálculo de la pendien-
| te.

Figura 8: Representación de la pierna y su modelo asociado.

También fue necesario calcular la curvatura natura de la pierna para que el soporte calce de

la manera más ergonómica posible. Para esto se utilizó papel aluminio y se moldeó la forma

de la pierna a la altura donde se ubicará posteriormente el LiDAR. El radio del circulo que

define esa curvatura es 166.73 mm.


Figura 9: Curvatura de la pierna.

A continuación se adjuntan los modelos diseñados.


Base curvada para soporte a la pierna. | Rampa de nivelación para el láser.

Figura 10: Soporte mecánico.

Finalmente, se adjunta la pieza renderizada, impresa y montada.


Piezas renderizadas


Montaje de Pruebas en Físico

Figura 11: Soporte mecánico.

## 6. Presupuesto inicial

Para el desarrollo de este proyecto se necesita contemplar el presupuesto, expuesto en la tabla

3, para construir el prototipo inicial.

Descripción | Precio | Comentarios/Justificación
Banda de compresión muslera | $11.100 | Soporte para pruebas: en esta banda se montará el sistema del LiDAR para reali- zar pruebas previas a la propuesta de ins- talación del sensor en la prótesis.
Filamento Impresión 3D PLA 1.75 mm 2 kg | $26.000 | Soporte para pruebas: se necesita impri- mir el soporte donde montaremos el Li- DAR y demás componentes del sistema junto al agarre a la banda.
Kit 830 Puntos de Conexión Componentes Electrónicos | $10.760 | Soporte para pruebas: se necesitan com- ponentes varios para hacer pruebas y pro- totipos.
Tornillos M2.5 8 mm (100 uds) | $6.581 | Soporte para pruebas: para unir las dos partes del prototipo 3D que agarran a la banda.
Velcro Autoadhesivo | $7.480 | Soporte para pruebas: se utilizará para po- der remover y ubicar fácilmente la batería en la banda utilizada. Se pegará una ban- da de velcro a la batería que usaremos pa- ra alimentar el sistema con el objetivo de que sea más simple cargarla.
Batería de alimentación | $11.790 | Soporte para pruebas: se utilizará para ali- mentar el sistema (5000 mAh).
IMU BNO085 | $28.678 | Implementación: se utilizará para determi- nar el ángulo de inclinación de la pierna en tiempo real. Comentario: no se encontró un proveedor local confiable y a un precio razonable.
Conversor 12V-5V | $4.205 | Alimentación aislada LIDAR 2D.
Raspberry Pi 5 shield | $6.280 | Solicitado por la contraparte para mayor modulación en la aplicación.
Nivel Digital | $26.432 | Permite aislar la linea de comunicación en- tre LIDAR 2D y Raspberry Pi 5
Aislador Digital ADUM1201 | $2.158 | Para realizar mediciones confiables y pre- cisas de niveles de inclinación para validar las pruebas y resultados.
Módulo Regulador de Voltaje 3.3V AMS1117 | $2.456 | Permite reducir voltaje de 5V a 3.3V

Multiplexor I2C de 8 Canales
TCA9548A
$2.983 | Controlar el uso de Comunicación I2C
Total | $146.903

Tabla 3: Presupuesto Hito 1

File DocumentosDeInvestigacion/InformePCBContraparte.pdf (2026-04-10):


PONTIFICIA UNIVERSIDAD CATOLICA DE CHILE ´

Instituto de Ingeniería Biológica y Médica

# iPre de Invierno: Desarrollo de una Power Distribution Board para prótesis de pierna robótica

PROFESORA: María Rodríguez

Vicente Maximiliano Corvalán Hernández vcorvalh@uc.cl

30 de septiembre de 2025

## 1. Propósito y alcance

Este documento registra cómo se implementó el diseño de la PDB 12V para Prótesis Robótica y provee una guía práctica para su uso, réplica y extensión por estudiantes o ingenieros. Se enfoca en arquitectura, conexiones, consideraciones de ensamblaje, verificación, pruebas y solución de fallas. No profundiza en la teoría de los convertidores.

## 2. Resumen del sistema

Entrada: Pack de baterías 12V (conector con llave).

Distribución: LTC3780 (buck-boost) para estabilizar 12V; derivación a 5V mediante LM2596 (buck 5 V) para Raspberry Pi y lógica.

Actuación: BTS7960 (puente H) para motor 12V (señales RPWM/LPWM, R EN/L EN).

Emergencia: SRD-05VDC para disminuir inductancia en DC Link; 1N4007 en bobina (flyback) y en línea 12V (bloqueo retorno).

Protecciones: En botón de emergencia para evitar peaks de voltaje por la inductancia y la alta corriente.

Sensado angular: AS5600 (I²C) por I²C (no es cubierto en la elaboración de este informe).

## 3. Especificaciones eléctricas (referenciales)

Parámetro | Símbolo | Valor | Observación
Rango entrada BAT | VBAT | 10−12.6 V | Pack de baterías Makita
Rail regulado | V12V | 12.0 V | LTC3780, buck-boost
Ondulación 12 V | ∆V12V | < 200 mVpp | Objetivo de validación
Rail lógica | V5V | 5.0 V | LM2596, salida a Raspberry
Ondulación 5 V | ∆V5V | < 50 mVpp | Con 470 µF local
Corriente de prueba motor | IMOT | 1 A | Ensayo continuo
Interfaz control puente H | EN/PWM | — | Pull-down en entradas

Cuadro 1: Especificaciones eléctricas de referencia del sistema PDB

1

## 4. Conectores y pinout

### 4.1. Alimentación y distribución

Conector | Pins | Asignación | Observación
CN1 | 2 | 1: +12V 2: GND | Input de alimentación del PDB
CN2 | 2 | 1: 12V 2: GND | Salida rail regulado a potencia para motor drive
CN3 | 3 | 1: LPWM 2: L EN 3: L IS | Pines de control puente H
CN4 | 3 | 1: RPWM 2: R EN 3: R IS | Pines de control puente H
CN5,6,7,8 | 2 | 1:+5V 2:GND | Pines de alimentación para lógica
CN9 | 2 | 1:BTN IN 2:BTN OUT | Botón de emergencia y control de relé

Cuadro 2: Conectores de alimentación y distribución

### 4.2. Control de puente H (BTS7960 (puente H))

Conector | Pins | Asignación | Observación
J-HCTRL | 6 | 1:RPWM 2:LPWM 3:R EN 4: L EN 5: 5V 6: GND | Entradas con pull-down/up
J-MOTOR | 2 | 1: M+ 2: M- | Salida a motor 12 V

Cuadro 3: Interfaz de control y potencia del puente H

## 5. Procedimiento de encendido (bring-up)

1. Energizar BAT y verificar encendido de LEDs “on”de módulos LTC3780 y LM2596.
2. Verificar rail 12 V (salida LTC3780 (buck-boost)). Verificar que UVLO no esté activado, en caso de error, ajustar potenciómetro más cercano a la entrada de la batería.
3. Habilitar 5 V (LM2596 (buck 5 V)). Verificar 5.0V ± 5 y rizado < 50pp con 470 µF.
4. Conectar carga lógica (Raspberry). Confirmar arranque sin brown-out.
5. Conectar puente H y motor. Probar EN bajos (estado seguro), luego PWM a baja frecuencia/duty.
6. Escalar a 1 A de carga en motor; registrar rizado, caída de tensión y temperatura de módulos.
7. Activar botón de emergencia y comprobar que no hay alimentación en CN2.

2

## 6. Pruebas de validación

### Eléctricas

Rizado y caídas: medir en 12 V y 5 V con diferente carga de amperaje.

Transitorios: arranques/inversión de dirección; observar estabilidad de EN/PWM.

Relé: conmutación y supresión de flyback (1N4007).

### Térmicas

Monitor de temperatura sobretodo en BTS7960 (puente H) en caso de haber cambiado motor a alguno que requiera mayor amperaje.

## 7. Recomendaciones para futuros diseños (layout y cableado)

Separar retornos de alta corriente (motor) y control; unir en estrella cerca de BAT.

Considerar las corrientes de retorno para evitar cross-talk en los voltajes de control del puente H.

Minimizar bucles de conmutación; planos anchos en 12 V y GND; 470 µF o superior lo más próximo a la salida.

Tener cuidado con el calor al soldar/desoldar componentes, pues pueden haber componentes antiguos en los módulos implementados que pueden tener problemas con altas temperaturas.

## 8. Instrucciones JLCPCB

Para enviar la PCB a fabricar a China en JLCPCB se ir a https://jlcpcb.com y clickear en “Order Now”. Luego, se debe agregar los archivos Gerber como se muestra a continuación:


3

Subir el archivo Gerber y continuar con la compra agregando al carro. Poner ojo al método de envío ya que puede haber uno más barato en el mismo tiempo. Finalmente, revisar el carro y dar click en “Secure Checkout”.

En caso de haber algún inconveniente con la PCB se les contactará a través del correo de la cuenta creada en JLCPCB.

## 9. Anexos

### 9.1. Esquemático de la PCB diseñada


### 9.2. Layout de la PCB diseñada


Figura 1: Top

4


Figura 2: Bottom

### 9.3. Código simple de prueba (Arduino/ESP32)

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

#d ef i n e LPWM 26 | // LPWM

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

void se tup ( ) {
l e d c S e t u p ( chR , f r e q , r e s ) ;
l e d c S e t u p ( chL , f r e q , r e s ) ; ledcA t tachPin (R PWM, chR ) ; ledcA t tachPin (L PWM, chL ) ; }

void loo p ( ) {
// Adelan te : sube y baja
rampTo ( 0 , | VMAX, | STEP ) ; | // 0 | +VMAX
rampTo (VMAX, 0 , | −STEP ) ; | // +VMAX | 0

5

d ela y ( 3 0 0 ) ; | // pausa b re ve

// Reversa : sube y baja ( n ega ti vo )
rampTo ( 0 , −VMAX, −STEP ) ; | // 0 | −VMAX
rampTo(−VMAX, 0 , | STEP ) ; | // −VMAX | 0

d ela y ( 3 0 0 ) ;
}

## // −−−−−−−−−−−−−−−− Funcione s −−−−−−−−−−−−−−−−

void se tMo to r ( i n t spd ) {
spd = c o n s t r a i n ( spd , −255, 2 5 5 ) ;
i f ( spd > 0 ) { | // a d el a n t e
l e d cW ri t e ( chL , 0 ) ;
l e d cW ri t e ( chR , spd ) ;
} e l s e i f ( spd < 0 ) { | // r e v e r s a
l e d cW ri t e ( chR , 0 ) ;
l e d cW ri t e ( chL , −spd ) ;
} e l s e { | // s to p ( c o a s t )
l e d cW ri t e ( chR , 0 ) ;
l e d cW ri t e ( chL , 0 ) ;
}
}

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

f o r ( i n t v = fromVal ; ( s t e p > 0 ) ? v <= toVal : v >= toVal ; v += s t e p ) { se tMo to r ( v ) ;
d ela y (STEP TIME ) ;
}
}

Notas de uso (resumen).

PWM a 20 kHz sobre ESP32 (ledc*); resolución 8 bits. Ajustar freq/res según

| | 6

ruido/linealidad.

Sin pines EN: las entradas del BTS7960 deben tener pull-down para estado seguro al encender.

Evita inversiones bruscas: el perfil hace rampa a 0 antes de invertir sentido.

Verifica límites de corriente del motor y alimentación antes de subir VMAX.

### 9.4. Documentos

https://uccl0-my.sharepoint.com/:f:/r/personal/marodriguezf_uc_cl/Documents/iPREs%20pr%C3%B3tesis/Vicente%202025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 (https://uccl0-my.sharepoint.com/:f:/r/personal/marodriguezf_uc_cl/Documents/iPREs%20pr%C3%B3tesis/Vicente%202025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)

7

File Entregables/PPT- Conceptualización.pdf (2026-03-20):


## Integración de Percepción Geométrica Basada en LIDAR 2D para Anticipación de Terreno en Prótesis Transfemoral Activa

Grupo 2

IEE3112 - Proyecto de Título


Las prótesis transfemorales activas (prótesis sobre rodilla con actuadores) han avanzado en actuadores, electrónica y control basado en sensores internos. Sin embargo, operan bajo control reactivo, sin información del entorno.

Esto limita la capacidad de anticipar terreno y adaptarse de forma segura. La incorporación de percepción (LIDAR) permite avanzar hacia prótesis más inteligentes.

## Contexto

## Estado actual del proyecto


La prótesis sin el LiDar ya posee un grado de avance correspondiente
a un TRL 7, contando con lo siguiente:

Estructura principal
Sensores EMG
Electrónica de potencia y batería
Socket
Computador de control basado en Raspberry Pi 5
Actuadores en la articulación de la rodilla

## Objetivos

Integración física de un LIDAR sin afectar funcionalidad mecánica Diseño de arquitectura de alimentación y comunicación
Procesamiento en tiempo real (≥ 10 Hz, latencia ≤ 200 ms)
Detección y segmentación: suelo, rampas, escalones y obstáculos Estimación geométrica: Distancia frontral de obstáculos (0.3–3 m), inclinación (error < ±2.5°), altura de escalones (erros < ±3 cm)
Generación de salidas para el controlador de la prótesis para futuro control anticipativo

## Contexto TRL y Financiamiento


TRL 4:
Prototipo validado en laboratorio que se ejecutará en un entorno controlado para
medir errores geométricos.

Financiamiento: $500.000 pesos chilenos.
Gastos de operación
Fabricación del prototipo
Componentes electrónicos (Sensores complementarios / adaptadores,
reguladores, cables, conectores, entre otros)
Diseño y fabricación de soporte para LIDAR
Impresión 3D
Validación experimental

## Metodología

Ventajas

Para el proyecto se utilizará una
metodología Scrumban con la siguiente
estructura:

Mayor flexibilidad sin perder
eficiencia
Transparencia en el equipo y
mejorar colaboración
Mejora continua e incremental,
ideal para proyectos complejos
Reducción de la sobrecarga de
los integrantes

Flujo de trabajo visual en Notion
Sprints de una semana
Comunicación diaria vía Whatsapp para
exponer los avances individuales
Reuniones al finalizar cada sprint
Roles flexibles para los integrantes en
función de las capacidades

## Planificación y Recursos

Se disponen 13 semanas
de trabajo

Hito 1: Propuesta
Conceptual y Diseño
Funcional

Hito 2: Prototipo

5 semanas de trabajo
1 semana exposición

5 semanas de trabajo
1 semana exposición
Presentación
final

1 semana exposición
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

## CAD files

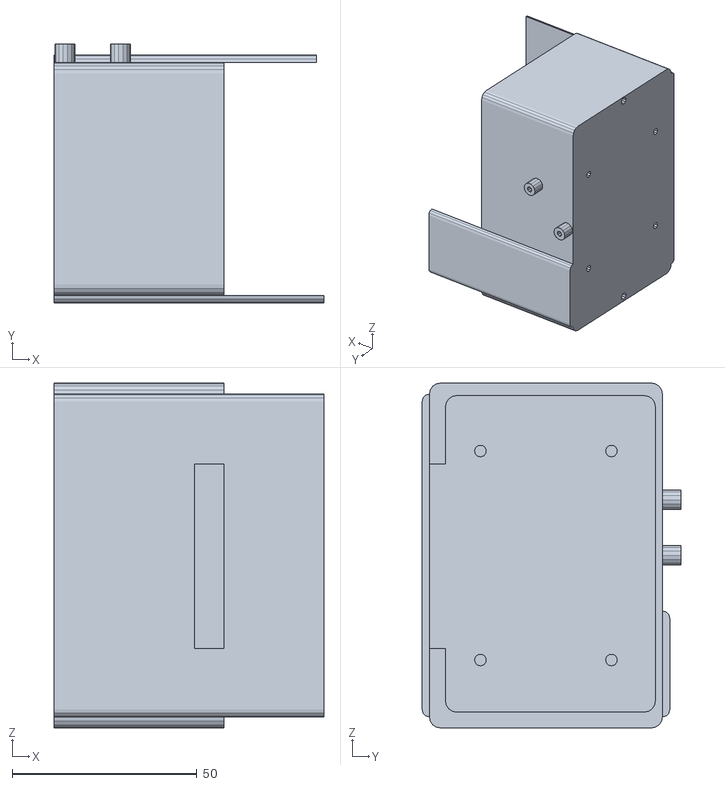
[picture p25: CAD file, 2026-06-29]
Modelos3D/CarcasaPCBs.stl
73.0 x 70.0 x 93.3

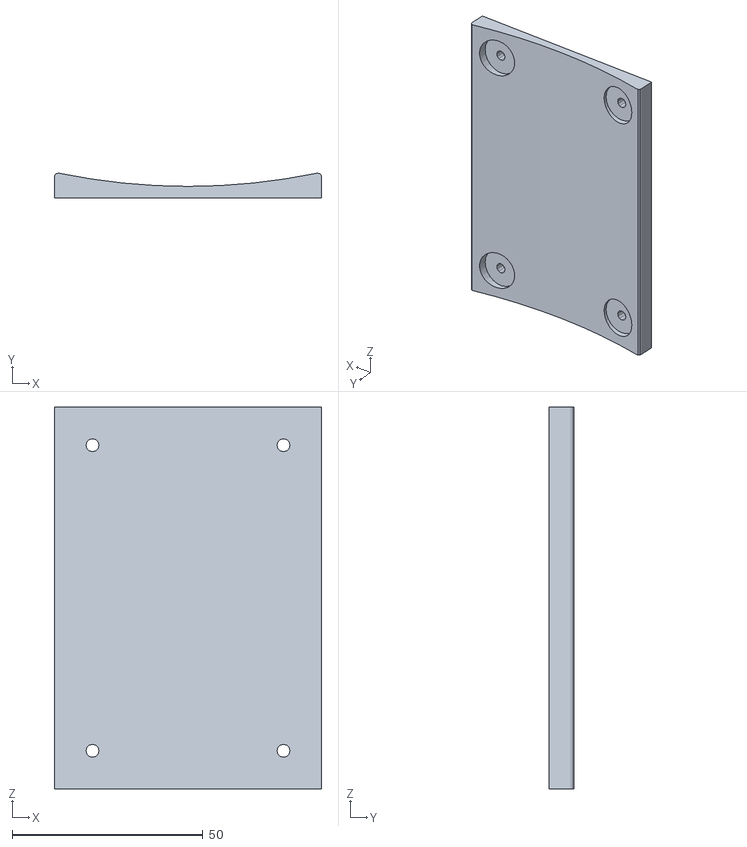
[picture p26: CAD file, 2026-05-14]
Modelos3D/BaseMuslera.stl
70.0 x 6.46 x 100.0

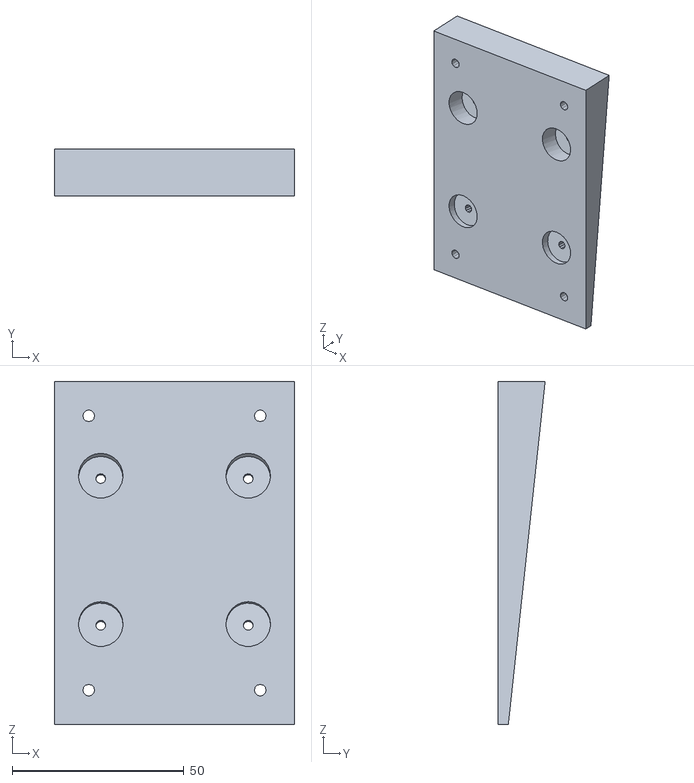
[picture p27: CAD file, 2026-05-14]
Modelos3D/FijadorMuslera.stl
70.0 x 13.8 x 100.0

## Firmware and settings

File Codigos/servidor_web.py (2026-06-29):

import os, json, csv, datetime
from flask import Flask, Response, stream_with_context, request, jsonify

app = Flask(__name__)
cola_global    = None
filas_guardadas = 0          # contador de frames guardados en esta sesión
CSV_CRUDO_PATH    = 'dataset_lidar_crudo.csv'     # LiDAR crudo interpolado + IMU en vivo
CSV_NIVELADO_PATH = 'dataset_lidar_nivelado.csv'  # LiDAR nivelado interpolado + etiquetas

# ==========================================
# RUTAS FLASK
# ==========================================

@app.route('/')
def index():
    return HTML_PAGE


@app.route('/stream')
def stream_datos():
    def generate():
        while True:
            try:
                paquete = cola_global.get(timeout=0.4)
                datos = {
                    'cruda':       [[float(p[0]), float(p[1]), int(p[2])]
                                    for p in paquete['cruda']],
                    'nivelada':    [[float(p[0]), float(p[1]), int(p[2])]
                                    for p in paquete['nivelada']],
                    'interpolada':       [float(v) for v in paquete['interpolada']],
                    'interpolada_cruda': [float(v) for v in paquete['interpolada_cruda']],
                    'imu': {
                        'accel': [float(v) for v in paquete['imu']['accel']],
                        'gyro':  [float(v) for v in paquete['imu']['gyro']],
                        'grav':  [float(v) for v in paquete['imu']['grav_promedio']],
                        'roll_deg':  float(paquete['imu_roll_deg']),
                        'pitch_deg': float(paquete['imu_pitch_deg'])
                    }
                }
                yield 'data: ' + json.dumps(datos) + '\n\n'
            except Exception:
                yield ': keepalive\n\n'

    resp = Response(stream_with_context(generate()), mimetype='text/event-stream')
    resp.headers['Cache-Control']     = 'no-cache'
    resp.headers['X-Accel-Buffering'] = 'no'
    return resp


@app.route('/api/guardar', methods=['POST'])
def guardar_frame():
    """
    Recibe { frame: {...}, labels: {...} } y añade una fila a CADA UNO de los
    dos datasets:
      - CSV_CRUDO_PATH:    LiDAR crudo interpolado (sin nivelar por IMU) + IMU en vivo + etiquetas.
      - CSV_NIVELADO_PATH: LiDAR nivelado interpolado + etiquetas (sin datos de IMU).
    Crea los CSV con encabezados si no existían.
    Devuelve { status, total_filas } para que el frontend actualice el contador.
    """
    global filas_guardadas
    data  = request.get_json(force=True)
    frame = data.get('frame', {})
    etiq  = data.get('labels', {})

    imu   = frame.get('imu', {})
    accel = imu.get('accel', [0.0, 0.0, 0.0])
    gyro  = imu.get('gyro',  [0.0, 0.0, 0.0])
    grav  = imu.get('grav',  [0.0, 0.0, 0.0])
    roll_deg  = imu.get('roll_deg',  0.0)
    pitch_deg = imu.get('pitch_deg', 0.0)

    interp_cruda    = frame.get('interpolada_cruda', [0.0] * 450)
    interp_nivelada = frame.get('interpolada',        [0.0] * 450)

    ts = datetime.datetime.now().isoformat(timespec='milliseconds')

    # ---------- Archivo 1: LiDAR crudo interpolado + IMU en vivo + etiquetas ----------
    # Orden fijo: dist_0..dist_449, IMU (accel, gyro, grav, roll, pitch),
    # binarios (sup_frontal, sup_trasera, esc_frontal, esc_trasera, obstaculo),
    # floats (ang_sup_frontal, ang_sup_trasera, altura_escalones, dist_obstaculo).
    # Sin columna de timestamp.
    fila_crudo = (
        list(interp_cruda)
        + list(accel) + list(gyro) + list(grav)
        + [roll_deg, pitch_deg]
        + [
            etiq.get('sup_frontal', 0),
            etiq.get('sup_trasera', 0),
            etiq.get('esc_frontal', 0),
            etiq.get('esc_trasera', 0),
            etiq.get('obstaculo',   0),
        ]
        + [
            etiq.get('ang_frontal', 0.5),
            etiq.get('ang_trasero', 0.5),
            etiq.get('altura_esc',  0.0),
            etiq.get('dist_obs',    0.0),
        ]
    )
    ya_existe_crudo = os.path.exists(CSV_CRUDO_PATH)
    with open(CSV_CRUDO_PATH, 'a', newline='') as f:
        w = csv.writer(f)
        if not ya_existe_crudo:
            header = (
                [f'dist_{i}' for i in range(450)]
                + ['imu_accel_x', 'imu_accel_y', 'imu_accel_z']
                + ['imu_gyro_x',  'imu_gyro_y',  'imu_gyro_z']
                + ['imu_grav_x',  'imu_grav_y',  'imu_grav_z']
                + ['imu_roll_deg', 'imu_pitch_deg']
                + ['sup_frontal', 'sup_trasera', 'esc_frontal', 'esc_trasera', 'obstaculo']
                + ['ang_sup_frontal', 'ang_sup_trasera', 'altura_escalones', 'dist_obstaculo']
            )
            w.writerow(header)
        w.writerow(fila_crudo)

    # ---------- Archivo 2: LiDAR nivelado interpolado + etiquetas ----------
    fila_nivelado = (
        [ts]
        + list(interp_nivelada)
        + [
            etiq.get('sup_frontal', 0),
            etiq.get('ang_frontal', 0.5),
            etiq.get('sup_trasera', 0),
            etiq.get('ang_trasero', 0.5),
            etiq.get('esc_frontal', 0),
            etiq.get('esc_trasera', 0),
            etiq.get('altura_esc',  0.0),
            etiq.get('obstaculo',   0),
            etiq.get('dist_obs',    0.0),
        ]
    )
    ya_existe_nivelado = os.path.exists(CSV_NIVELADO_PATH)
    with open(CSV_NIVELADO_PATH, 'a', newline='') as f:
        w = csv.writer(f)
        if not ya_existe_nivelado:
            header = (
                ['timestamp']
                + [f'lidar_nivelado_{i}' for i in range(450)]
                + ['sup_frontal', 'ang_frontal',
                   'sup_trasera', 'ang_trasero',
                   'esc_frontal', 'esc_trasera',
                   'altura_esc',  'obstaculo',  'dist_obs']
            )
            w.writerow(header)
        w.writerow(fila_nivelado)

    filas_guardadas += 1
    return jsonify({'status': 'ok', 'total_filas': filas_guardadas})


# ==========================================
# PÁGINA HTML
# ==========================================

HTML_PAGE = """<!DOCTYPE html>
<html lang="es">
<head>
<meta charset="UTF-8">
<meta name="viewport" content="width=device-width, initial-scale=1.0">
<title>LIDAR+PROTESIS 2026 · LiDAR + IMU Monitor</title>
<link href="https://fonts.googleapis.com/css2?family=JetBrains+Mono:wght@300;400;600&family=Space+Grotesk:wght@500;600&display=swap" rel="stylesheet">
<style>
*, *::before, *::after { box-sizing: border-box; margin: 0; padding: 0; }
:root {
  --bg:     #050e1a;  --panel:  #08152a;  --border: #0f2340;
  --accent: #00ffa3;  --amber:  #f59e0b;  --blue:   #3b82f6;
  --violet: #a78bfa;  --text:   #d4e4f7;  --muted:  #4a6887;
  --danger: #ef4444;
}
body { background:var(--bg); color:var(--text); font-family:'Space Grotesk',sans-serif; height:100vh; display:flex; flex-direction:column; overflow:hidden; }
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

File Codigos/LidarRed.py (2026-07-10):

import torch
import torch.nn as nn

class LidarCNN(nn.Module):
    def __init__(self):
        super(LidarCNN, self).__init__()
        # Entrada: [Batch, 1, 450]
        self.lidar_red = nn.Sequential(
            nn.Conv1d(in_channels=1, out_channels=16, kernel_size=5, stride=2, padding=3),
            nn.BatchNorm1d(16), 
            nn.ReLU(), 
            nn.MaxPool1d(kernel_size=2), 
            
            nn.Conv1d(in_channels=16, out_channels=32, kernel_size=5, stride=2, padding=2), 
            nn.BatchNorm1d(32), 
            nn.ReLU(), 
            nn.MaxPool1d(kernel_size=2), 
            
            nn.Conv1d(in_channels=32, out_channels=64, kernel_size=3, stride=1, padding=1),
            nn.BatchNorm1d(64),
            nn.ReLU(),
            # CAMBIO: Reducimos de 8 a 4 para bajar la cantidad de parámetros al aplanar
            nn.AdaptiveAvgPool1d(4) 
        )
        
        # Rama donde juntamos todo
        # Tamaño de entrada = (64 * 4 del LiDAR) = 256 
        self.fc_lidar = nn.Sequential(
            # CAMBIO: Dropout agresivo justo después del aplanado
            nn.Dropout(p=0.3), 
            nn.Linear(256, 64), # CAMBIO: Reducimos las neuronas ocultas de 128 a 64
            nn.BatchNorm1d(64), # CAMBIO: Un BatchNorm extra aquí ayuda mucho a regularizar
            nn.ReLU(),
            nn.Dropout(p=0.5), # CAMBIO: Aumentamos el Dropout final de 0.2 a 0.5
            # CAMBIO: Aumentamos el Dropout final de 0.2 a 0.5
            nn.Linear(64, 5) # Salida lineal de 5 neuronas
        )

    def forward(self, lidar):
        if lidar.dim() == 2:
            lidar = lidar.unsqueeze(1)
            
        x_lidar = self.lidar_red(lidar)
        x_lidar = torch.flatten(x_lidar, start_dim=1) 
        
        output = self.fc_lidar(x_lidar) 
        
        return output

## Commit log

2026-04-18 tabla de presupuesto
    [TablaDePresupuestos.csv]
2026-04-24 códigos servidor software y Modelos 3D hardware :rocket:
    [Base_LIDAR_JLL_1.stl, Base_LIDAR_JLL_2.stl, Pieza lidar 1.stl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]
2026-06-29 Actualización Hito 2
    [BaseMuslera.stl, Base_LIDAR_JLL_1.stl, Base_LIDAR_JLL_2.stl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]
